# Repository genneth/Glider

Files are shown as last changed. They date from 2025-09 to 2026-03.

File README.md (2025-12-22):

# Glider

Open-source Eink monitor with an emphasis on low latency.

Note: This repo only contains the hardware design, the gateware running on the FPGA is my open-source [Caster EPDC](https://gitlab.com/zephray/Caster/) design. This README also contains information about the Caster as well.

Hardware Photo

This is a long document, containing not just information about this project, but also pretty much everything I know about Eink. Given it's a bit hard to gather information about Eink online, I think this is the right thing to do. Use the following table of contents to navigate around.

Eink is a registered trademark and brand of E Ink Corporation. All the contents provided in this repo are based on publicly available information online and original research. They are not endorsed by Eink in any way and they may contain errors and/ or inaccuracies. 

If you're interested in attaining a board, checkout the [product page for the Modos Paper Monitor on Crowd Supply](https://www.crowdsupply.com/modos-tech/modos-paper-monitor).

If you are interested in Eink or any other display technologies, I have a Discord server for that. Feel free to join: [https://discord.gg/rtT7euSHQS](https://discord.gg/rtT7euSHQS) . (This Discord server is also not endorsed by Eink or any other company. It's not a customer support server.) For Modos product support or other inqueries about Modos products, use [https://discord.gg/6ktE6VxSyh](https://discord.gg/6ktE6VxSyh).

## Table of Contents 

- [Overview](#overview)
    - [Features](#features)
    - [Hardware](#hardware)
    - [Components](#components)
- [Eink Screens](#eink-screens)
    - [Basic Theory of Operation](#basic-theory-of-operation)
    - [Advantages and Disadvantages](#advantages-and-disadvantages)
    - [The Role of Eink Controller](#the-role-of-eink-controller)
    - [Screen Panel Types](#screen-panel-types)
    - [Using Screen with Integrated Controller](#using-screen-with-integrated-controller)
    - [Using Screen without Integrated Controller](#using-screen-without-integrated-controller)
    - [Understanding Waveform](#understanding-waveform)
    - [Greyscale Display](#greyscale-display)
    - [Color Display](#color-display)
    - [Dithering](#dithering)
    - [Eink Screen Generations](#eink-screen-generations)
- [Caster/ Glider Design](#design-of-caster-and-glider)
    - [Low Latency Drive](#low-latency-drive)
    - [Hybrid Greyscale Mode](#hybrid-greyscale-mode)
    - [Limitations](#limitations)
    - [Hardware Design Decisions]()
    - [Gateware Architecture](#gateware-architecture)
    - [Firmware Functions](#firmware-functions)
    - [Resources Utilization](#resources-utilization)
- [Building](#building)
    - [PCB](#pcb)
    - [FPGA Bitstream](#fpga-bitstream)
    - [MCU Firmware](#mcu-firmware)
    - [Flashing Board](#flashing-board)
    - [Compatible Screens](#compatible-screens)
- [References](#references)
- [License](#license)
- [Appendix](#appendix)
    - [Using Screens without Datasheet](#using-screens-without-datasheet)
    - [Screen List](#screen-list)

## Overview

### Features

- Complete solution for low-latency/ high-refresh-rate EPD monitor
- Supports electrophoretic display panels with parallel I/F (Eink(R), OED and DES)
- Supports both monochrome and color-filter-array (such as Kaleido(TM)) based color screen
- Extremely low processing delay of \<20 us
- Supports binary, 4-level grayscale, and 16-level grayscale output modes
- Latency-optimized binary and 4-level grayscale driving modes
- Hybrid automatic binary and 16-level grayscale driving mode
- Host software runtime controllable regional update and mode switching
- Hardware bayer dithering, blue-noise dithering, and error-diffusion dithering with no additional latency
- Controller takes standard HVsync signal input
- Board-level design supports USB-C (USB Type-C DisplayPort Alt Mode) and DVI input

### Hardware

r0p7_mb

- Xilinx(R) Spartan-6 LX16 FPGA running Caster
- DDR3-800 framebuffer memory
- Type-C DisplayPort Alt-Mode video input with onboard PTN3460 DP-LVDS bridge or
- DVI (via microHDMI connector) video input with onboard ADV7611 decoder
- Epaper power supply with up to 1A peak current on +/-15V rail supporting large panels
- VCOM kick-back voltage measurement support
- On-board STM32H750 microcontroller for USB communication and firmware upgrade
- Up to 133MP/s processing rate with dithering enabled, >200MP/s when disabled

The board is designed with KiCad. You may need the latest stable version of KiCad to open the source file.

### Components

This repo hosts the PCB design and firmware source code. The RTL code is in a separate repo: [https://gitlab.com/zephray/Caster/](https://gitlab.com/zephray/Caster/).

## Eink Screens

Eink is the brand of a family of paper-like electrophoretic displays. The underlying technology is invented in the MIT Media Lab between 1995 and 1997 by Barrett Comiskey, J.D. Albert, and Joseph Jacobson. They later founded the E Ink Corporation to commercialize this technology.

Nowadays they are commonly used on e-readers and electronic shelf labels. You’ve probably seen them on Kindle, in stores, or maybe in some train stations as well.

| eReader/ Tablets | Electronic Shelf Label | Digital Signage |
|-|-|-|
| app_ereader | app_esl | app_signage |

(Source: https://www.eink.com/application, image copyright Eink corporation)

This section gives an overview of the electrophoretic displays, including the screen panels available and underlying technology. Note this project doesn't and can't support all electrophoretic screens. This documentation also solely focuses on using existing off-the-shelf screen panels rather than the physics or manufacturing process of one.

### Basic Theory of Operation

In the simplest form, you have charged particles with different colors, dispersed in some oil in some transparent container. By applying electric fields the particles can be moved up or down to produce either black or white, or a mixture of that.

eink-particle

(Source: https://www.eink.com/tech/detail/How_it_works , copyright Eink Corporation)

There are multiple technologies based on this basic concept, namely Eink’s micro-capsule display, SiPix (now acquired by Eink)’s micro-cup display, and WFT’s DES display. They differ in specific ways of confining the particles in containers, but otherwise very similar.

The pixels on the screen are typically arranged as a 2D array, driven with TFTs. The pixels are scanned/ driven periodically at a fixed refresh rate, typically ranging from 50Hz to 120Hz. Applying positive voltage on the pixel will typically drive the particles toward the white state while applying negative voltage will drive the particles towards the black state. This is similar to active matrix TN/IPS LCDs, which also use 2D TFT arrays and electrical fields for changing state. However, unlike LCDs, EPDs maintain their state after the electrical field is removed. So unlike LCDs which require continuous refreshing, the EPDs only need to be refreshed till the pixels are fully driven.

In terms of driving the screen panel, depending on the pixel value (1 or 0), each pixel would be driven either with a positive voltage or a negative voltage. A global counter can be used to count the frames elapsed and stop driving the pixels after a predefined period of time (for example, 100ms). Two framebuffers are typically used for determining if the pixel has changed color or not. If not, then the pixel does not need to be driven.

### Advantages and Disadvantages

In terms of display quality, EPDs are no match for modern IPS LCDs. The following is a comparison table of key parameters. The specific number would vary depending on the screen used but should be within the same ballpark.

| | Monochrome EPD | CFA-based Color EPD | Transmissive TFT IPS LCD | Reflective TFT TN LCD |
|-|-|-|-|-|
| Contrast Ratio | ~17:1 | ~14:1 | ~1000:1 | ~14:1 |
| Colors | 16 (Greyscale) | 4096 | 16M | 256 |
| Color Gamut | N/A | ~1.5% sRGB | ~99.9% sRGB | N/A |
| Reflectivity | ~45% | ~25% | N/A | ~15% |
| Response Time | ~150ms | ~150ms | ~10ms | ~15ms |

It has a few advantages. It reflects lights instead of emitting lights, so it generally consumes less power and can be used outdoors, etc. It’s also bistable, which means that it retains the image after the power has been removed. Personally, the biggest differentiating factor for me (author of this README) is that it looks like paper.

rlcd-vs-eink

The image above shows a comparison between reflective TFT LCD (SHARP memory LCD in this case) and Eink. The LCD has a mirror-like texture which changes reflectivity drastically in different angles, while the Eink is more paper-like.

| ZBD LCD | Ch LCD | STN LCD |
|-|-|-|
| zbd | chlcd | stnlcd |
| Bistable, reflective, high contrast, no greyscale, ~10s refresh | Bistable, reflective, lower contrast, up to 32 level greyscale, ~5s refresh | Volatile, reflective, lower contrast, up to 32 level greyscale, ~100ms response |

There are many other reflective or bistable display technologies. They are all interesting displays on their own, but none of them feels like paper (yet).

Overall, there is no single perfect display technology. Each has its own unique strength. Pick the right one for your project.

### The Role of Eink Controller

The Eink controller is in some ways similar to the display controller (DC/ CRTC) + timing controller (TCON) in a typical LCD-based system. It takes the raw image data and converts it to signals required to drive the screen.

eink-controller

To understand the actual work of an eink controller, start from the basic concept. The color of a pixel can be changed by applying positive or negative voltage for a finite period of time. From the controller’s perspective, depending on the current state of the pixel and the desired state of the pixel, there are 4 possibilities.

| Current State | Target State | Action |
|-|-|-|
| Black | Black | No operation |
| Black | White | Apply positive voltage |
| White | Black | Apply negative voltage |
| White | White | No operation |

The controller needs to store and maintain the screen state inside of its own buffer memory, so it would typically have a large on-chip SRAM or an off-chip SDRAM controller. The controller should also have a timer to ensure the screen doesn't get overdriven or underdriven.

The controller often uses the so-called "[waveform](#understanding-waveform)" to replace the action column of the previous table. Instead of hardcoding the action for state transition, the actions are stored into a look-up-table (LUT) which can be modified at runtime to allow higher flexibility.

Controllers may also offer more advanced features such as [dithering](#dithering) acceleration, multiple region updates, automatic LUT selection, etc.

### Screen Panel Types

As discussed in the previous section, an Eink screen needs to be coupled to an Eink controller to function. Aside from that, the screen also needs high-voltage drivers to drive the TFTs and the pixels. Virtually all E-paper panels use either COG (Chip-on-Glass) or TAB (Tape Auto Bonding) to integrate some chips onto the screen panel itself. Most of the screens available today can be divided into two categories based on whether or not the controller is integrated in:

screen-types

Here is a non-exhaustive list of the types based on their size: (the size or resolution is not related to or limited by the type, it is just for a certain size, and the vendors tend to make them the same type.)

- Screens without controller: 4.3", 6.0", 7.8", 8.0", 9.7", 10.3", 13.3", 25.3", 31.2", 42"
- Screens with controller: 1.02", 1.54", 2.13", 2.6", 2.9", 3.71", 4.2", 5.65", 5.83", 7.5", 12.48"

One may notice that almost all e-readers/ e-ink cellphones use screens without controllers, while almost all e-ink electronic shelf labels (ESL) use screens with controllers. This gives some hints about the advantages and disadvantages of two types:

| | Without Controller | With Controller |
|-|-|-|
| System Cost | High. A dedicated controller or SoC with an integrated controller is usually required. Needs a dedicated power supply. | Low. Virtually any MCU could drive the screen directly, and the power supply is integrated in. |
| Greyscale Levels | Generally 16 (4bpp), up to 32 (5bpp) | Generally 2 (BW only) or 4 (2bpp), with some hack, up to 16 (4bpp) |
| Refresh Speed | Generally fast (100ms~300ms) for BW. Depends on the screen used and the system architecture | Generally fast (100ms~300ms) for BW if the partial refresh is enabled. Greyscales are much slower, BWR or BWY screens would be even slower.
| Total Update Latency | Generally the same as refresh time. Depends on the system architecture | Slow. Ranging from 100ms to several seconds based on the resolution. |

Please keep in mind the discussion is about off-the-shelf screens you can buy today. These tradeoffs do not necessarily come from the fact the controller is integrated or not.

Note that I mentioned the refresh speed and total update latency. They are different:

The refresh speed refers to the time it takes to start refreshing the screen: from starting to seeing screen changing, to the screen finish showing the new content.

The total update latency refers to the latency when the processor needs to update the screen, to the screen finish showing the new content. As you can see, this is the biggest issue for screens with controllers. This is the main reason why they are rarely used on e-readers cell phones or PC monitors.

screen-controller-diagram

This diagram illustrates the difference between the two. It should be noted that the screens without controllers have the flexibility to be driven quickly, but the system designer might not architect the system for low latency.

### Using Screen with Integrated Controller

Screens with integrated controllers have almost everything already integrated. Common display panels of this type only need a few external capacitors, inductors, and MOSFETs to support the integrated bipolar power supply circuit, then it could be hooked up to MCUs or MPUs using common interfaces like SPI or I2C. There are a lot of driving boards and examples of these screens available online.

To be expanded (TODO)

### Using Screen without Integrated Controller

This could get complicated. Note I used a lot of "generally" in the previous comparison table because there are many things one could do to drive them. Some of them would certainly impact the performance. The main issue here is the controller chip. There are three solutions to drive these screens:

- Using a dedicated controller chip to drive the screen
- Using an SoC that has an integrated controller
- Using a fast MCU/SoC to emulate the controller with GPIO (software timing controller)

Then, again here is a comparison between them:

| | Specialized controller chip | SoC with integrated controller | MCU + Software TCON |
|-|-|-|-|
| Resolution | UXGA+ | UXGA+ | Limited by MCU RAM. Up to XGA with SRAM, UXGA with PSRAM, UXGA+ with DDR |
| Greyscale | Up to 32 | Up to 32 | Up to 32 |
| Partial Update | Yes | Yes | Yes |
| Total Update Latency | Depends. Could be very close to refresh speed, could be slow like screens with controller | Same as refresh speed | Same as refresh speed if data is internally generated (not streaming from an external device such as a PC) |
| Suitable Applications | IoT devices, E-readers, cellphones, E-ink monitors. possibly E-ink laptops | Advanced IoT devices, E-readers, cellphones, E-ink typewriters, possibly lower performance E-ink laptops | When using MCU: IoT devices, large ESLs, simple DIY E-readers. When using MPU: Same as SoC with integrated controller |

When using a dedicated controller, it could accept data from external devices. This allows it to be used in various different types of applications. Ranging from IoT devices, and ESLs, to PC monitors with relatively fast refresh rate and low latency.

When using SoC or MCU, the display content is generated by the SoC or MCU itself, which ultimately is limited by the capability of the SoC or MCU. Given the current SoCs with E-ink display controllers are usually limited in performance, the application is limited. The same goes for MCU, it does what an MCU could do. You could find ways to stream video data into SoC or MCUs by using USB, camera interface, WiFi, etc., but this might not be optimal.

#### Existing Solutions

- Specialized controller chip
    - Closed-source
        - EPSON S1D13xxx: Widely used EPD controller in early E-readers. Proprietary, no documents available. Probably EOL.
        - IT8951: Used on the waveshare EPD Hat. Documents are available. It works with large EPDs up to 2048x2048. The drawback is the speed as the interface between processor and IT8951 could be slow. This is similar to the situation on screens with integrated controller
        - T1000: Also known as IT8957, upgraded model of IT8951. It supports even higher resolution. It features a higher speed MIPI DSI interface to mitigate the slow speed of IT8951.
        - Waveshare HDMI driver board: FPGA-based controller. Closed source but easily purchasable, could be integrated into larger projects as a module.
    - Open-source
        - This project (Caster + Glider): FPGA-based controller, multiple update modes, ultra-low latency processing, and wide range of screen support.
        - https://hackaday.io/project/21607-paperback-a-desktop-epaper-monitor: FPGA-based controller. However, doesn't support partial update mode and slower speed.
        - https://hackaday.io/project/21168-fpga-eink-controller: FPGA-based controller supports vendor waveform with reasonable speed.
- SoC with integrated controller
    - RK29xx: Fairly old, Cortex-A8 based (RPi 1 level performance), 55nm, EOL
    - RK3026/RK3028: Fairly old, Cortex-A9 based (RPi 2 level performance), 40nm, EOL
    - i.MX 50: Fairly old, Cortex-A8 based (RPi 1 level performance), 65nm, in production
    - i.MX 6ULL: Cortex-A7 based (RPi 1 level performance), 40nm, in production
    - i.MX 6S/D: Fairly old, Cortex-A9 based (RPi 2-3 level performance), 40nm, in production
    - i.MX 7S/D: Cortex-A7 based (RPi 2 level performance), 28nm, in production
    - i.MX 8ULP: Cortex-A35 based (RPi 2 level performance), 28nm FD-SOI, in production
    - AW B200: Cortex-A53 based (RPi 2 level performance), 28nm, in production
    - MT8113: Cortex-A53 based (RPi 2 level performance), 12nm, in production
    - RK3566/RK3568: Cortex-A55 based (RPi 3 level performance), 22nm, in production
    - RK3576: Cortex-A72 + A53 based (RPi 4-5 level performance), 8nm, in production
- MCU/SoC + Software TCON
    - http://essentialscrap.com/eink/waveforms.html: One of the earliest e-ink hacks. Limited in performance but still could be used as a reference
    - NekoCal: One of the earliest e-ink software TCON with greyscale support. Used to be available as a DIY kit. No longer updated, still could be used as a reference
    - InkPlate 6/10: Commercially available. Based on ESP32.
    - EPDiy: Based on ESP32, supports a lot of different screens, recommended if want to build some device with ESP32+Eink or embed it into a larger project.

#### Interface Signals and Timing

The interface signals and timing are fairly similar to LCDs without a controller. Following is the list of signals typically found on EPDs:

- GDOE/ MODE: Gate driver output enable
- GDCLK/ CKV: Gate driver clock (like HSYNC in LCD)
- GDSP/ SPV: Gate driver start pulse (like VSYNC in LCD)
- SDCLK/ XCL: Source driver clock (like PCLK in LCD)
- SDLE/ XLE: Source driver latch enable (like HSYNC in LCD)
- SDOE/ XOE: Source driver output enable
- SDCE/ XSTL: Source driver start pulse (like DE in LCD)
- SD: Source driver data (8-bit or 16-bit)

SD signals go into the source driver, typically in the X direction. GD signals go into the gate driver, typically in the Y direction. It's a 2D array, the gate driver selects one line at a time, and the source driver outputs the voltage for all the pixels in that line.

Conceptually, it's like a raster scan on a CRT. To send one field of data, both GD and SD are reset to the start position by using the start pulse signal. Data are then transmitted into the source driver 4 or 8 pixels at a time. Once the line has been fully transmitted, the source driver is reset to the beginning position by a start pulse signal, and the gate driver moves to the next line by a pulse on the gate driver clock. Once all lines have been scanned, the entire process repeats for the next field.

One notable difference with LCD is that each pixel is represented by 2 bits. This, however, doesn't mean each pixel is 2bpp or 4-level greyscale. The 2-bit per pixel is used to encode the voltage applied to the pixel:

- 00: No voltage
- 01: Negative voltage
- 10: Positive voltage
- 11: No voltage

Just like CRT/ LCD, there are also blanking periods in the entire timing (which means it's just waiting without active pixel data being sent). They have identical meanings to CRT/ LCD systems:

display-timings

(Source: https://projectf.io/posts/video-timings-vga-720p-1080p/, Copyright Will Green)

The following is a piece of pseudo-code implementing the Eink timing:

```c
#define DATA_BUS_WIDTH      8 // 8bit wide bus
#define PIXEL_PER_CYCLE     (DATA_BUS_WIDTH / 2)
#define VFP     12  // Vertical front porch
#define VSYNC   1   // Vertical sync length
#define VBP     2   // Vertical back porch
#define VACT    758 // Vertical active lines
#define HFP     72  // Horizontal front porch
#define HSYNC   2   // Horizontal sync length
#define HBP     2   // Horizontal back porch
#define HACT    (1024 / PIXEL_PER_CYCLE)

void pulse_h_clock() {
    sdclk = 1;
    sdclk = 0;
}

void drive_line(bool v_in_act) {
    sdce = 1;
    gdclk = 0;
    for (int i = 0; i < HFP; i++) pulse_h_clock();
    sdle = 1;
    gdclk = 1;
    for (int i = 0; i < HSYNC; i++) pulse_h_clock();
    sdle = 0;
    for (int i = 0; i < HBP; i++) pulse_h_clock();
    if (v_in_act) sdce = 0;
    for (int i = 0; i < HACT; i++) {
        send_data();
        pulse_h_clock();
    }
}

void drive_frame() {
    gdoe = 0;
    sdoe = 0;
    gdsp = 1;
    for (int i = 0; i < VFP; i++) drive_line(false);
    gdsp = 0;
    gdoe = 1;
    sdoe = 1;
    for (int i = 0; i < VSYNC; i++) drive_line(false);
    gdsp = 1;
    for (int i = 0; i < VBP; i++) drive_line(false);
    for (int i = 0; i < VACT; i++) drive_line(true);
}
```

More explanation can be found at [http://essentialscrap.com/eink/index.html](http://essentialscrap.com/eink/index.html)

### Understanding Waveform

The waveform is a look-up table for the eink controller to determine how to drive the pixels, mostly useful for greyscale image display, but generally used for binary image display as well.

The look-up-table has 3 inputs (dimensions): frame number, source grayscale level, and destination grayscale level. During the update process, for a certain pixel, the source and destination level stays the same, and the frame number increases each frame. The look-up process is done for every pixel every frame. The controller may choose different LUTs depending on the ambient temperature. Mode switching is also implemented by simply switching between different LUTs.

This is essentially what typically eink controller does. For each pixel, look up in the table to determine the voltage to use. Repeat this for a couple of frames with an incrementing frame counter, until all pixels are fully driven.

It should be obvious that the waveform file itself is independent of the resolution as the waveform only cares about a single pixel. With an incorrect or un-optimal waveform, the screen should at least display some recognizable image.

#### Waveform Example

There are several sample waveform tables provided in the project repo. Take the GC16 (Greyscale clearing 16-level) waveform of GDEW101C01 as an example: https://github.com/zephray/NekoInk/blob/master/waveform/gdew101_gd/test_M2_T0.csv

Take one line from that file:

```6,13,0,0,0,0,0,0,0,0,0,2,1,1,1,1,1,1,1,1,1,1,2,2,2,2,2,2,2,2,2,2,2,2,2,2,2,2,1,0```

This means from greyscale level 6 to level 13, it needs to go through the following sequence. Each number means the operation on that frame, 0 is no-operation, 1 is darken, and 2 is lighten. In this case, there are 38 frames, first 9 frames do nothing, then lighten for 1 frame, darken for 10 frames, lighten for 16 frames, and finally darken for 1 frame and have no operation for the last frame. This is the sequence to change a pixel from level 6 to level 13. Such lookup is done for every pixel on every frame.

#### Waveform Modes

To give system designers more flexibility, Eink controllers often offer multiple "modes", like binary mode, 16-level grayscale mode, 16-level grayscale mode with reduced flashing, 4-level grayscale mode, etc.

The waveform provided by Eink has many modes. There is a good document from Eink describing the modes:

https://www.waveshare.net/w/upload/c/c4/E-paper-mode-declaration.pdf

It provides a good overview of the modes. I am just going to add some comments.

- GC in the GC16 stands for "greyscale clearing". GC does not stand for greyscale. There are 16-level greyscale modes that aren't called GC16.
- Officially there are no 32-level greyscale modes (yet). There are 5-bit waveforms, which means they internally use 5 bits for each pixel, which potentially allows up to 32-level greyscale, but no such waveform exists (yet).
- There are no 16-level greyscale modes without flashing. The DU4 is the only greyscale mode that's non-flashing.
- The GL16 mode, as described, only works for black text on a white background. When refreshing greyscale images, the GL16 is similar to the GC16.
- The GLR16 mode is also called the REGAL mode, and the GLD16 mode is also called the REGAL-D mode.
- Eink doesn't even know if it should be spelled as REAGL or REGAL:  Google search "REAGL site:eink.com" and "REGAL site:eink.com" both returned several results.
- Eink-provided waveform usually implements all these modes, however it is not always required. The waveform file may also contain waveform tables in other orders.
- In terms of the waveform, the waveform for GL16, GLR16, and GLD16 are identical. This is expected, the REGAL requires an additional algorithm on the host image processing and is not a technology based on tweaking the waveform.

#### Obtaining Waveform

In general, the screen vendor (Eink, Good Display, etc.) should provide the waveform file.

If your screen has a flash chip on it, it's also possible to extract the waveform from a flash dump:

```dd if=somedump.bin of=waveform.wbf bs=1 skip=2182```

If you have access to an application board, it might also be possible to extract the waveform there. For example, if the system uses a T1000/T2000/T2001 controller, the waveform is usually stored in the SPI flash connected to the controller. Some times the waveform stored on the flash is compressed (in addition to the RLE compression already applied to the waveform file itself).

#### Waveform Formats

E-Ink distributes waveforms in the wbf file format. SoC/ Eink controller hardware often requires converting the file into a vendor-specific file format. Caster/ Glider also uses a specific binary format. This project defines a common human-readable format (Interchangeable Waveform Format, IWF) and provides several tools for working with different binary formats and the IWF format.

#### Interchangeable Waveform Format

The waveform consists of one descriptor file in iwf extension (ini format) and various lut data files in csv format.

The descriptor contains the following required fields:

- VERSION: the version of the descriptor (should be 2.0)
- NAME: (optional) original name for the waveform
- BPP: (optional, default 4) 4 or 5, representing the internal state count used for waveform
- PREFIX: the filename prefix for actual waveform files
- MODES: the total modes supported by the waveform
- TEMPS: the total number of temperature ranges supported by the waveform
- TxRANGE: the supported temperature in degC, where x is the temperature ID
- TUPBOUND: (optional) upper bound for temperature range, each range is TxRANGE to Tx+1RANGE (or TUPBOUND in case of the last one)
- TABLES: total number of LUTs inside the waveform
- TBxFC: the frame count for the table, where x is the LUT ID

Each mode has its own mode section named [MODEx], where x is the mode ID, containing the following fields:

- NAME: the name for that mode
- T*TABLE: the table used for the temperature in that mode

There should be a number of LUTs, saved in the filename like PREFIX_TBx.csv, where x is the LUT ID. Each csv file should contain a LUT like this: lut[src][dst][frame], which means, to transition from src greyscale level to dst greyscale level, at a certain frame in a frame sequence, what voltage should be applied to the screen (0/3: GND / Keep, 1: VNEG / To black, 2: VPOS / To white). Each line contains the frame sequence for one or more source-to-destination pairs.

For example:

- ```4,7,1,1,1,0,2``` means to transition from greyscale level 4 to greyscale level 7, there should be 5 frames, each applying VNEG VNEG VNEG GND VPOS
- ```0:14,15,2,2,2``` means to transition from any greyscale level between 0 and 14 to greyscale level 15, there should be 3 frames, each applying VPOS VPOS VPOS

These are provided to only illustrate the file format, they are not valid or meaningful Eink driving sequences.

#### Converting Between Waveform Formats

The following converters are provided in the repo:

- To convert from iwf to fw (iMX6/7 EPDC format): ```./mxc_wvfm_asm v1/v2 input.iwf output.fw```
- To convert from fw to iwf: ```./mxc_wvfm_dump v1/v2 input.fw output_prefix```
- To convert from wbf to iwf: ```./wbf_wvfm_dump input.wbf output_prefix```

#### Waveform Tweaks

Some commercial implementations allow users to reduce the frame count and/ or alter the waveform playback speed, so the user can trade between contrast ratio and frame rate.

### Greyscale Display

Other than full white and full black, with appropriate modulation, Eink screens can also display some levels of greyscale (typically 16).

![greyscale](assets/eink_32g.jpg)

For grayscale displays, the basic idea is simple. If the pixel is not fully driven (say only drives for 50ms while it takes 100ms to reach full black/ white), it would stay in a gray state.

There are two ways of achieving this modulation:
- Modulate the frame time
- Modulate the number of frames with constant frame rate

Both are possible, as described below

#### Frame Time Modulation

This method changes the drive time by changing the length of a single frame. The screen would only be driven for 15 or 31 frames for 16-level and 32-level greyscale, but the frame time (thus frame rate) is altered to provide the desired driving time. The LUT would be a one-dimension look-up table, only containing the incremental time required to drive to the next greyscale level. The source/ gate driver output enables the line to be toggled to achieve the desired driving time.

This method doesn't seem to be implemented in any commercial solutions and is significantly slower than the second method. But it certainly works. The 32-level greyscale demo shown in the picture above is achieved using this method.

#### Frame Count Modulation

This method changes the drive time by changing the number of frames being applied to the screen. The screen is still being driven at a constant frame rate. The following is a simplified hypothetical waveform table for achieving 4-level greyscale:

| Previous State | Target State | Frame 0 | Frame 1 | Frame 2 | Frame 3 | Frame 4|
|-|-|-|-|-|-|-|
| Black | Black | NOP | NOP| NOP | NOP | NOP |
| Black | Dark Grey | VPOS | VNEG | VPOS | NOP | NOP |
| Black | Light Grey | VPOS | VNEG | VPOS | VPOS | NOP |
| Black | White | VPOS | VNEG | VPOS | VPOS | VPOS |

Note how it alternates between VPOS and VNEG in the beginning. This is often called the "activation phase" to improve the contrast ratio. Putting this detail aside, it changes the number of VPOS frames to settle down on different grey levels.

The actual grayscale driving sequence used in the commercial implementation is more complex than that, often involving switching the pixel towards black/white a few times before settling. This design is partially due to the limited time control granularity and other temperature/ manufacturing variance-related concerns. Some side-effects of such a driving sequence are that the refreshing process is “flashing”, and is slower compared to displaying only a 1-bit binary image.

### Color Display

There are several different technologies that could be used to build full-color EPDs. The 2 most common ways are to use a color-filter-array (CFA) or use a multi-pigment color display.

The following picture has a CFA-based color screen (Kaleido 3) on the left, and a multiple pigment color display (Spectra 6) on the right, displaying the same image.

![sp6vsk3_2](assets/isabella.jpg)

![sp6vsk3](assets/kaleido3spectra6.jpg)

(Yes the left one IS a color screen!)

#### Color Filter Array

CFA stands for color filter array, which is colored glass/ film on top of the screen pixel. This is also the technology used on most color LCDs. Eink Kaleido, Eink Triton, and color DES are based on this technology. The main advantage is that it's relatively simple to control, and the low-level driving is the same with the greyscale panels. Thus it has the same level of refreshing time (100~200ms), and the same level of greyscale (16 level translate to 16^3=4096 colors). The drawback is that the CFA filters out some light (due to its colored nature), and the screen reflectivity is negatively affected by the CFA. The screen ends up being quite dark. Up to now, most color E-readers use CFA-based displays. This project supports all three major types of CFA-based EPD screens: color DES screen, Eink Triton, and Eink Kaleido.

#### Case Study: GDEW101C01 (CFA-based, DES)

The GDEW101C01 is a 10.1" color DES screen made by Good Display / WeiFeng Tech. It uses CFA to produce color images. As a result, to the eink controller hardware, it's just a normal greyscale panel with a bunch of pixels. However, the pixels are colored depending on their location due to the CFA. The coloring of the pixels can be either handled by hardware or software.

##### Pixel Arrangement

Color DES is a bit different from a typical color TFT LCD in terms of CFA design. Typically on TFT LCDs, one RGB pixel is called a pixel, and each R/G/B component is called as a sub-pixel. On color DES, the sub-pixel ends up being called a pixel, and each pixel is either red, green, or blue. In the display industry, such pixels are more commonly referred to as dots.

![subpixel](assets/subpixel.jpg)

Pengo, CC BY-SA 3.0 https://creativecommons.org/licenses/by-sa/3.0, via Wikimedia Commons

The actual photo of the DES panel under the microscope:

![color-des](assets/color_des.jpg)

In the above photo, the DES pixel arrangement is the same as the OLPC XO-1. Notably, many Eink's Kaleido 3 (but not all) also uses the same pixel arrangement.

Having no subpixel / each pixel only has 1 color doesn't necessarily mean that the effective resolution needs to be divided by 3. This arrangement is slightly more "efficient" than the RGB strip in terms of perceptive resolution. You can find a more detailed analysis in the paper Comparing the Effective Resolution of Various RGB Subpixel Layout.

##### Processing image for Color DES

If the image is displayed on color DES without any processing, it would look like a greyscale image. This is similar to when you just send the same color value to R/G/B components on a color LCD.

To get color, there are 2 possible solutions:
- Treat 4 pixels as a group of a single pixel, and each physical pixel is now considered as a subpixel.
- Treat each pixel as an independent pixel, but send only the color component that corresponds to the pixel color.

Depending on how you classify pixel and subpixel, the 2nd method can also be viewed as a mean of 2X supersampling subpixel rendering.

In general the 2nd method offers better resolution especially in text:

| Method 1 | Method 2 |
|-|-|
| ![des_without_spr](assets/des_without_spr.png) | ![des_with_spr](assets/des_with_spr.png) |

The following discussion are all about the 2nd method: render at full resolution, but only use 1 color component for each pixel.

![pixel-layout](assets/PixelLayoutDiagonal.png)
(Source: https://wiki.laptop.org/go/File:PixelLayoutDiagonal.png, public domain)

For example, for pixel 01, the pixel on the screen is green. Then only the green component from the frame buffer should be sent to the screen.

To get a basic 4096 color image display, this is everything needed. However generally to improve image quality, a few more steps are applied:

##### Low pass filtering

The previously described image-displaying process is essentially a down-sampling process for each color component: Only 1/3 of the pixels are sent to the screen. Then this becomes a classic signal processing issue: sampling the signal would cause frequency components above Nyquist to fold back to the low frequency part. Or in simpler words, you would see jagged edges/ aliasing, which are things that weren't present in the original image. To prevent this, low pass filtering (blurring) needs to be applied first to the image to remove these high-frequency components. The following diagram from the OLPC wiki shows a simple way of implementing a such filter:

![pixel-proc](assets/PixelProcDiagonal.png)
(Source: https://wiki.laptop.org/go/File:PixelProcDiagonal.png, public domain)

##### Dithering

Dithering can be applied to further improve image quality. See the dithering section for more details.

#### Multi-Pigment Color Display

Another technology for implementing color EPD is by using a multi-pigment color display. This is a technology developed initially by SiPix and further improved by Eink. The basic idea is to use ink particles with different colors inside a single pixel. By applying a sequence of voltages, the ink particles can be arranged to display different colors.

![spectra6](assets/eink_spectra6.jpg)

(Source: https://www.eink.com/tech/detail/How_it_works , copyright Eink Corporation)

One major advantage of this solution is it can achieve higher resolution (because it doesn't have a CFA, so no resolution reduction), higher reflectivity (because it doesn't have a CFA, so no light loss), and higher color saturation (because it doesn't have a CFA, no need to play the reflectivity vs saturation trade-off game).

Eink has 2 lines of products using this Technology, Eink Gallery and Eink Spectra. The advantage is it's much brighter compared to CFA-based solutions. The disadvantage is it's much more difficult to drive, and quite slow: 1st /2nd gen Eink Gallery screen takes 30s (!) to refresh, and Spectra 6 Plus devices take 7s to refresh. It's possible to trade in some color saturation for higher speed, though still much slower than CFA-based solutions. The specific product lines will also be discussed in [Eink Screen Generations](#eink-screen-generations)

##### How ACeP Waveform Works

To be written (TODO)

##### How to get more colors on ACeP

This is possible with a modified waveform.

To be written (TODO)

##### Fast ACeP

While ACeP screens have been generally slow to refresh (15-30s), Eink has tried to improve that. In 2022 Eink released their Gallery 3 lines of ACeP screens, which promised sub 1 second update time. [ACeP was supposed to be the "next big thing" in ereader](https://arstechnica.com/gadgets/2022/04/new-e-ink-gallery-displays-could-finally-make-full-color-e-readers-good/). Back in the end 2022, Eink announced that ["Gallery 3 has moved into mass production, with customer products from Bigme, BOOX, iFlyTek, iReader, PocketBook, Readmoo, and AOC coming down the pipeline in 2023 and beyond"](https://www.e-ink-info.com/e-ink-gallery-3-acep-color-epaper-displays-move-mass-production).

How well does it do? Just talking about the screen, it's not looking good. It suffers from poor reflectivity and poor saturation to a point where it's not much better than Kaleido:

![gallery3_kaleido](assets/gallery3_kaleido_plus.jpg)

(Original illustration copyright MiHoYo)

The difference between Gallery 3 and Gallery Palette (which is supposed to be a lower-end product) is also stunning:

![acep_comparison](assets/gallery3_gallerypalette.jpg)

The one on the left is the Gallery 3 used on eReaders, and the one on the right (brighter and more saturated one) is the Gallery Palette used on ESLs. Though to be honest I hacked the right one a bit to display 512 colors opposed to the stock 7 colors. If Gallery 3 had the same image quality as previous ACeP/ Gallery screens, it would make sense to trade in response time for better image quality. But it doesn't.

##### Future of ACeP

While as previously referenced that Eink was hoping to ship lot of Gallery 3 based E-readers in 2023, 2023 passed with exactly one product, the Bigme Galy, with mixed receptions. Early 2024, it was announced that [Bigme Galy has been discontinued](https://goodereader.com/blog/electronic-readers/bigme-galy-is-discontinued), and [Eink has announced EOL for certain ACeP-based products](https://www.ineltek.com/wp-content/uploads/2024/04/EInk_AC073TC1_EOLNoticeLetter_notice_20240401.pdf). But ACeP is not dead yet.

Going forward, Eink has 3 different line-ups for different markets:
- Eink Marquee for outdoor signage
- Eink Spectra for electronic shelf labels and advertisements
- Eink Gallery for e-readers and e-notebooks

All of these lines are direct offspring of the original ACeP screens:
- Eink Marquee uses the same color composition as the ACeP, but replaces the SiPix-style micro-cup with micro-capsule
- Eink Spectra uses similar structure as the ACeP, but replaces color composition
- Eink Gallery is the original ACeP line up

In 2024, we saw the release of reMarkable Paper Pro, which is a 11.8" Gallery 3 e-notebook. ACeP screens are still in production and we might be able to see more products in the future.

##### Spectra 6

Compared to the Gallery lines, Spectra 6 uses a very similar multiple pigment system. But instead of using cyan, magenta, and yellow as the base colors, Eink switched to use red, yellow, and blue instead. Officially the color gamut volume stays the same, but the contrast ratio gets boosted up to 22:1 from 10:1, mainly due to darker black. Reflectivity stays the same at around 35%, lower than Carta products, but still far better than CFA based ones.

(TODO: Compare image quality between Sp6 and GalleryPlus)

### Dithering

Eink and DES panels typically only support up to 16 levels of greyscale with the vendor-provided waveform. To improve response time, or to avoid flashing images, a binary (1-bit, 2-level) display is also used. Dithering could be applied to produce better images (increasing SNR, in signal processing sense).

The following is applying dithering to a simple black-to-white gradient. Note the results are not optimal due to limitations in quantization and incorrect gamma correction. But the idea is the same.

| Original | Binary No-dithering | 2 Row Sierra Dithered |
|-|-|-|
| ![original](assets/grad_orig.png) | ![nodither](assets/grad_no_dither.png) | ![errordiffusion](assets/grad_ed.png) |

Dithering can help when the screen has a native 16-level greyscale as well:

| Original | 16 Level Greyscale No-dithering | 16 Level Greyscale Dithered |
|-|-|-|
| ![original](assets/grad_orig.png) | ![nodither](assets/grad_4bpp_nd.png) | ![errordiffusion](assets/grad_4bpp_ed.png) |

As you can see, the non-dithered image loses all the greyscale in between, while the dithered version on the right gives the illusion of greyscale while only using full black and full white colors.

To understand it further, take the following example:

Say the source image is 30% brightness (or 0.3). This cannot be displayed on a binary screen which can only display 0% (0.0, black) or 100% (1.0, white) brightness. A simple thresholding process is added to determine if the screen should display 0 or 1 by checking the incoming brightness. If it's less than 0.5 then the display brightness is rounded down to 0, otherwise 1. Because 0.3 is always lower than 0.5, the whole screen displays 0 (black).

This is less than ideal. A better way is to set around 30% of the pixel black, while 70% of the pixel white. Different dithering algorithms can be used to achieve this 30/70 distribution. Two common methods used are ordered dithering and error-diffusion dithering, which will be described below.

#### Ordered Dithering

The ordered dithering adds a pre-computed/ fixed texture to the image before the thresholding process. In other words, it basically adds some noise to the image. This may sound weird initially, but it should be easy to see the effect of noise in the example.

Using the example previously described displaying 30% brightness grey on a binary screen. The goal is to let the rounding process end up with 0 for 30% of the time and 1 for 70% of the time. This could be achieved by adding a noise. In the simplest case, a random number with a uniform distribution between [-0.5, 0.5] is added to the incoming brightness. The brightness has a value of 0.3, when adding this number to the random number, the random number now has a uniform distribution between [-0.2, 0.8]. The threshold is still set to 0.5, and now the probability distribution can be seen as below:

![pdf](assets/dithering_pdf.svg)

The pixel now has a 30% chance of being rounded up to 1, and a 70% chance of being rounded down to 0. Before dithering, it would always be rounded down to 0.

However, a purely random number is generally not the best noise to use. Bayer dithering matrix and blue noise are more commonly used, with the results as illustrated below. The idea is the same, but instead of adding random numbers, a pre-computed number from the Bayer dithering matrix (array) or blue noise texture (array) is added to the image.

| Random Dithering| Bayer Dithering | Blue-noise Dithering |
|-|-|-|
| ![random](assets/grad_rand.png) | ![bayer](assets/grad_bayer.png) | ![bluenoise](assets/grad_bn.png) |

#### Error-Diffusion Dithering

The basic idea is when rounding down the color (selecting the closest color from the 16-level greyscale from 256-level input), the error value (difference) is calculated and added to neighboring pixels (so this error would be considered when processing these pixels later). The whole process is called error-diffusion.

Still using the previous example of a 30% brightness image, and assume an extremely simple dither kernel: diffuse all error to the next pixel. Let's see it in action.

In the first pixel, 0.3 (image brightness) is less than 0.5 (threshold), so it's displayed as 0 (black). This introduces a 0.3 error: the displayed color is 0.3 darker than the requested color. So 0.3 is being diffused to the next pixel, hoping the next pixel can correct the error.

Onto the second pixel. The value is 0.3 (image brightness) + 0.3 (diffused error) = 0.6. It's now larger than 0.5 (threshold), so it's displayed as 1 (white). This introduces a -0.4 error: the displayed color is 0.4 brighter than the requested color. -0.4 will be diffused to the next pixel.

For the 3rd pixel, the value is now 0.3 - 0.4 = -0.1. This is less than 0.5 and displayed as 0 (black). Error -0.1 is diffused further.

And this process just goes on. With enough pixels, eventually, it would yield about 30% of white pixels and 70% of dark pixels.

Similar to how random value is not the best thing to do in ordered dithering, dithering to the right is also less than ideal. It creates very repetitive patterns. I mentioned the word kernel. Error diffusing uses a diffusion kernel, which specifies the target and percentage of the diffused error. There are many classic kernels, such as Floyd-Steinberg, Stucki, Sierra, etc. commonly used for image dithering. They all diffuse to more than 1 pixel to improve the overall look of the image. As shown below, even just diffusing the error to 2 pixels (half of the error goes to the pixel on the right, and the rest half of the error goes to the pixel on the bottom) yields a much better result:

| Dither to Right | Right and Down | Floyd-Steinberg |
|-|-|-|
| ![right](assets/grad_naive.png) | ![rightdown](assets/grad_naive2.png) | ![fs](assets/grad_fs.png) |

#### Applying Dithering on CFA-based Color Screens

Dithering can be applied on CFA-based color screens such as Eink Kaleido and color DES screens as well. The following is on a simulated DES screen: (The left original is assuming the screen has a native 24bpp color, still on a simulated screen)

| 16M color DES (does not exist) | 8-color DES | 8-color DES Dithered |
|-|-|-|
| ![original](assets/color_8bpp.png) | ![nodither](assets/color_nd.png) | ![errordiffusion](assets/color_ed.png) |

Ordinary dithering kernels don't work too well on color screens. For example, the error-diffusion dithering process pushes/ diffuses error neighboring pixels without considering their color. Ideally, it should push/ diffuse the error only to pixels with the same color. This is fairly easy to fix though, by tweaking the kernel it would achieve good results on CFA-based screens as well. (I am going to shamelessly call it Wenting's kernel)

| 16M color DES (does not exist) | 8-color DES naively apply Floyd-Steinberg (wrong) | 8-color DES with Wenting's kernel |
|-|-|-|
| ![original](assets/color_8bpp.png) | ![original](assets/color_fs_wrong.png) | ![errordiffusion](assets/color_ed.png) |

Of course, one can apply Bayer-like ordered dithering, blue noise dithering, or dithering on 4096-color mode as well:

| 8-color DES Bayer-like | 8-color DES Blue-noise | 4096-color DES Error-diffusion |
|-|-|-|
| ![original](assets/color_bayer.png) | ![original](assets/color_bn.png) | ![errordiffusion](assets/color_4bpp_ed.png) |

It's called bayer because, similar to how naively doing error diffusion doesn't work, the bayer matrix has to be modified to work on the color screen.

#### Gamma Correction

Another thing to consider is gamma. The dithering process involves a step of selecting the closest value. However, selecting the closest numerical value does not necessarily mean the closest color. The image typically is in sRGB space, which is non-linear. This causes the simple rounding to pick the wrong color, also calculating the wrong error value. One solution is to work in the linear space. This is also known as gamma-aware dithering. You could read more related info online, for example here: [https://learnopengl.com/Advanced-Lighting/Gamma-Correction](https://learnopengl.com/Advanced-Lighting/Gamma-Correction).

![dither-gamma](assets/dither_gamma.jpg)

The difference is quite evident when dithering down to 1 bit for a color screen. The top left is the original image, the top right is dithering in the sRGB space, and the bottom left is dithering in the linear space.

#### Further Reading

See [https://en.wikipedia.org/wiki/Dither](https://en.wikipedia.org/wiki/Dither) for more information about dithering.

### Eink Screen Generations

Depending on how you count, there are multiple generations of Eink screens commercially available. For monochrome screens before 2023, it's possible to tell the generation by looking at the 6th digit on the serial number:

![eink_serial](assets/eink_serial.jpg)

That is the FPL code in the following table:

| FPL Platform | FPL Code | Panel Model    | Marketing Name          | First Introduced |
| ------------ | -------- | -------------- | ----------------------- | ---------------- |
| 2.0          | 0        |                |                         | ?                |
| 2.1          | 1        |                |                         | 2004             |
| 2.3          | 2        |                |                         | ?                |
| V100         | 3        |                | Vizplex                 | 2007             |
| V110         | 4        |                | Vizplex                 | 2008             |
| V110A        | 5        |                | Vizplex                 | 2008             |
| V220         | 6        | VA3200         | Pearl                   | 2010             |
| V250         | 7        |                | Pearl                   | ?                |
| V220E        | 8        |                | Pearl                   | ?                |
| V320         | 9, R     | VB3300         | Carta 1.2 / 1000        | 2013             |
| V320         | ?        | VB3300?        | Carta 1100              | 2019             |
| V400         | A, C     | VD1400/ VD1405 | Roadrunner / Carta 1200 | 2021             |
| V450         | ?        | VH1948         | Carta 1250              | 2021?            |
| ?            | ?        | VD1400/ VD1405 | Carta 1300              | 2023             |
| ?            | M        | ?              | Spectra (BWR)           | ?                |

Data points used to create the table above:
- The first commercialized Eink e-reader SONY Librie hit the market in 2004, *likely* with an ED060SC1 panel
- ED060SC1 has an FPL code of 1 on the barcode, meaning the 2.1 platform
- Multiple datasheets (like the one for ED060SC4) confirms the 6th digit marks the FPL code with mapping for V220/220E/320/400
- Inkwave's WBF decoder (originated from Kindle GPL kernel code) provides an FPL platform to an FPL code mapping table that matches well with info from the datasheet
- Kindle Oasis3 was reported to use a Carta 1100 screen, and it has an ED070KC3 screen with a V320 FPL platform
- Kindle PW5 was reported to use a Carta 1200 screen, and it has an ED068KC5 with a VD1405 panel model
- Kobo Clara BW was reported to use a Carta 1300 screen, and it has an ED060KHE with a VD1405 panel model
- The datasheet of ED068KC1 mentioned the name "Roadrunner" for the 400 platform, but that name never gets used outside of that. I would guess they were going to use the Roadrunner for the new generation but eventually fell back to Carta 1200 so it's more like an incremental improvement
- From the information available, it really looks like Carta 1000 and 1100 use the same film, and Carta 1200 and 1300 use the same film. If this is true, it may sound like a scam if they are named differently but use the same film. But this is actually okay. Just like how chips usually have a binning process, the same chip would sell under different product names with different performance levels. It's reasonable for Eink to do incremental improvements on the manufacturing process to yield better screens with the same film and call it under a different name, or simply binning screens to different grades and selling under different names.

I will let you decide how to count the generations.

For the CFA-based screens, the following generations of screens exist:

- Eink Triton: First generation color screen. Uses an RGBW glass color filter and square pixels. The underlying screen panel uses Pearl film.
- Eink Triton 2: 2nd generation color screen. Uses RGB glass color filter and stripe pixel. The underlying screen panel uses Pearl film.
- Eink Kaleido: 3rd or 2nd gen color screen depending on the definition. Uses an RGB color filter. Each pixel is still square, but each color covers 3 pixels. The underlying screen panel uses Carta film.
- Eink Kaleido Plus: 2nd gen Kaleido. Uses an RGB color filter. Each pixel is still square but different configurations exist. Some screens have each color covering 2 pixels, some others have each color covering only 1 pixel. The underlying screen panel uses Carta film.
- Eink Kaleido 3: 3rd gen Kaleido. There are at least 2 different configurations exist. One features RGB filter covering 1 pixel per color, the other features a 2R/2G/1B configuration, on average 5/3 pixels per color. The underlying screen panel uses Carta 1000/1200/1250/1300 film depending on the model.
- Eink Kaleido 3 Outdoor: Wide temperature version of Kaleido 3.

Most CFA-based color screen panels don't come with an integrated controller, but there are a few exceptions.

For the multiple-pigment color screens based on SiPix technology, the following generations of screens exist:

(Color abbreviation: B: black, W: white, R: red, Y: yellow, B: blue, C: cyan, M: magenta)

- Eink Spectra 3000: BWR or BWY 3 color screen.
- Eink Spectra 3100: BWRY 4 color screen.
- Eink Spectra 3100 Plus: BWRY 4 color screen. The orange display is now possible with driver circuit changes.
- Eink Spectra 6: RYBW 4 color screen. Can reproduce 6 primary different colors. Newer waveforms released by Eink increased this number to 10.
- Eink Spectra 6 Plus: RYBW 4 color screen. Still reproduces 6 different colors. Allows faster refresh compared to 6 with driver circuit changes.
- Eink Gallery (also known as Gallery 4000): CMYW 4 color screen (ACeP).
- Eink Gallery Plus (also known as Gallery 4000): CMYW 4 color screen (ACeP).
- Eink Gallery Palette (also known as Gallery Palette 4000)： CMYW 4 color screen (ACeP). Reproduce 7 different colors.
- Eink Gallery 3: CMYW 4 color screen (ACeP). Reproduce 8 different colors, much faster than other Gallery screens at the cost of lower saturation.

There are both integrated-controller Spectra/Gallery screens and controller-less Spectra/Gallery screens.

Additional notes regarding the multi-pigment color screens:

- ACeP, or Advanced Color ePaper refers to the CMYW 4 color screen. Is not a product line on its own
- To be honest, I don't know how many colors can be reproduced on Gallery or Gallery Plus screens based on public information. The spec sheets for [AC133UT1](https://www.beck-elektronik.de/fileadmin/user_upload/Produkte/BECK_Elektronik/Displays/Downloads/EPD/E-Ink/AC133UT1_Specs.pdf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) suggests it might be 8 colors. Eink claims 32000 or 60000 colors in their materials, but they also clarified these numbers refer to color gamut. In other words, they represent color saturation rather than a number of different colors that can be displayed on screen. Dithering is heavily used to display color images on Gallery screens.
- It's possible to achieve more colors on Gallery Palette screens. 7 is not a physical limit.
- The Gallery 4000 rebranding happened in [2020](https://www.linkedin.com/pulse/e-ink-gallery-4000-anna-rybalko/) however Eink never seems to use that name on their website.

## Design of Caster and Glider

This section describes the design specific to the Caster and Glider. The following is an overall block diagram showing both hardware and gateware components in the signal chain:

![Overall ABlockdiagram](assets/glider_overall_block_diagram.svg)

### Gateware Architecture

The FPGA gateware is divided into multiple modules. The caster.v is the top-level of the EPDC core design, but several additional components are connected under top.v to form a complete image processing system. Different components are generally inter-connected with synchronous or asynchronous (in case of clock domain crossing) FIFOs.

The top-level design has 3 major clock domains: clk_vi: Input video clock domain, running at ½ pixel rate. clk_epdc: EPDC clock domain, running at ¼ pixel rate. clk_mem: Memory clock domain, running at ¼ memory transfer rate.

To understand how it works, the following is a guided tour around the life cycle of a pixel.

Before an incoming pixel can be processed by the controller, the memif module needs to retrieve the local pixel state from the DDR SDRAM. Once the value is retrieved, it’s pushed into the state readout/ input FIFO (bi_fifo). At/ around the same time, the input video stream is pushed into the video input FIFO (vi_fifo).

The EPDC runs a local Eink timing generator for counting pixels and blankings. This timing should be a slightly delayed version of the incoming video timing. Once the local timing generator determines that it needs to output the pixel soon, the EPDC logic pops out one pair of the video input and state readout and starts processing.
Two values go through the video processing pipeline:

- Stage 1: This pipeline stage waits for the FIFO to output the data.
- Stage 2: The 8-bit input image is dithered down to 1-bit and 4-bit at this stage for later use.
- Stage 3: The waveform lookup is done at this stage for 16-level grayscale modes
- Stage 4: Based on the pixel state, the new state and voltage selection value are determined at this stage.
- Stage 5: The new state is pushed into the state writeback/ out FIFO (bo_fifo) and the voltage selection is sent to the screen.

The memif module later pops out the writeback value from the bo_fifo and writes it back to the DDR SDRAM.

The EPDC always processes 4 pixels per clock. For screens with different interface widths, a rate adapter is added after the EPDC output. Some logic is duplicated 2 or 4 times (such as the waveform RAM or the pixel decision logic), while some are extended and daisy-chained (such as the error diffusion dithering unit) to achieve the 4 pixels per clock throughput.

### Firmware Functions

The MCU manages housekeeping items as described below. It uses FreeRTOS as the operating system.

- EPD power supply: The power supply provides a common, source, and gate supply to the EPD panel. In addition to a basic on/off switch, the MCU can also adjust the VCOM voltage, and measure the optimal VCOM voltage of the panel installed. The VCOM measurement is done by isolating the VCOM supply from the screen while keeping the gate supply, scanning the screen with source = VCOM, and measuring the kick-back voltage on the VCOM.
- Power supply monitoring: The microcontroller monitors voltage and current of different rails, and ensure they are in the expected range.
- FPGA bitstream loading: The FPGA doesn’t have its own flash memory, the bitstream is pushed over SPI from the MCU to the FPGA upon powering up. In this way, the FPGA bitstream can be easily bundled together with the MCU’s firmware and updated together.
- Type-C negotiation: The onboard USB Type-C port can support video input in addition to powering the board using the USB-C DisplayPort Alt Mode. The MCU runs a USB-C PD stack to communicate this capability to the video source device over standard USB PD protocol. The MCU also controls the Type-C signal mux to remap the lanes to the correct place depending on the cable orientation.
- Video decoder initialization: The FPGA used on the board doesn’t have high-speed deserializers to interface with common high-speed video interfaces such as DisplayPort or DVI directly. Instead, dedicated video decoder chips are used on the board. They typically need initialization before use, and the MCU takes care of this. In this specific design, the DP decoder chip also handles AUX P/N line flipping based on the Type-C cable orientation.
- PC communication: One advantage of the Caster is that update modes and forced update/ clearing can be applied on a per-pixel basis. Software may utilize this to assign different modes to different windows or change update modes depending on the content on the fly. This is done by sending requests to the MCU over a USB connection. The MCU runs TinyUSB and presents itself as an HID device so it can forward messages between the host PC and the FPGA.

### Low Latency Drive

The Caster implements several techniques for reducing the latency, which will be explained here.

As described before, the existing basic driving method employs a global counter for looking up the waveform table. This imposes a limit on the global image update rate: the controller only accepts a new incoming image after the previous update is finished. The update usually takes about 100ms, translating to an image rate of 10Hz. Or, in other words, the user needs to potentially wait up to 100ms before the new image is even processed by the controller.

One way to mitigate this issue is by having multiple update regions. For example, imagine the user is typing a and b. In a single region controller design, a is drawn to the screen immediately, while the b needs to wait 100ms before it gets drawn. If the controller supports multiple regions, it could start drawing the letter b as soon as it’s typed, reducing the latency. This however requires the software to program the controller to correctly set the region to the letter boundary, and re-allocating regions on the fly as the number of regions is generally quite limited (like 4-16).

![caster-pipelined](assets/caster_pipelined_update.svg)

The Caster simply treats every pixel as an individual update region, for maximum flexibility and is transparent to the software.

Another latency optimization technique the Caster implemented is on the pixel that’s already being updated. For example, if the user types the letter a and deletes it right after. With the basic driving method, the controller needs to wait till the letter a is fully displayed before it can erase it. The previously proposed/ implemented regional update doesn’t help here because in this situation it’s about the same pixel so it has to be in the same region. The second technique is early cancellation. If a pixel changes before it’s fully driven, instead of waiting for it to be fully driven, it’s driven toward the requested input state, and the frame counter is updated depending on the newly calculated driving time.

![caster-early-cancel](assets/caster_early_cancel.svg)

By combining both, it’s then possible to implement low-latency binary and 4-level grayscale modes. The tradeoff between framerate and contrast ratio is also no longer relevant. Both a high frame rate and high contrast ratio are achieved automatically.

### Hybrid Greyscale Mode

As discussed previously, getting [greyscale](#greyscale-display) image on Eink is a sophisticated process, much slower than binary, and shows flashing images during the process. This poses challenges on how to make it useful for the users.

On eReaders, the software could switch between fast and slow modes based on the action. The eReader software may also simply not support things that don’t work well on the screen. For example, there might be no scrolling but only whole page flipping. What’s being done on existing eink monitors is throwing the problem back to the user. The user simply needs to accept that the update is slow, the latency is long, and the process is flashing.

What Caster implemented is allowing it to switch between the fast binary mode and slow greyscale mode automatically on a per-pixel basis. When the input image is changed, it switches to binary mode and does the update. When the image hasn’t changed for a while, it re-renders the image in greyscale.

### Limitations

The method does come with downsides: it requires much more memory bandwidth to implement. Taking a 1080P panel as an example (roughly 120 Mp/s (million pixels per second) with reduced blanking). With the traditional method, the controller only needs the old pixel state and the new pixel state (4bpp each) to determine the voltage needed or 8-bit/ 1-byte memory read per pixel. The bandwidth requirement is then 120Mp/s x 1B/pixel = 120MB/s. One single 16-bit SDR-133 SDRAM is more than enough to handle this. The Caster currently stores a 16-bit state per pixel (for 2 sets of old pixel values and pixel-specific timer counters), and the pixel state needs to be updated per frame, so the pixel state buffer alone requires 2-byte read and 2-byte write per pixel. It then takes another 0.5-byte per pixel to read the new image value from memory. 120Mp/s x 4.5B/pixel = 540MB/s. A 16-bit DDR-333 memory is then needed to implement this. The Glider hardware uses a DDR3-800 memory to allow even higher resolution. If the controller is not integrated inside an SoC (like our case, the controller is sitting inside the monitor, not part of your PC’s CPU/GPU), it also needs to use actual low latency video interfaces like DVI or DP, instead of simpler but slower interfaces like USB or I80/SPI. This could drive up costs as well. These techniques also don't help with use cases like reading books, so commercial e-reader solutions have little reason to spend the extra trouble to implement these.

### Hardware Design Decisions

To be written (TODO)

### Resources Utilization

The following numbers are for reference only and would vary depending on RTL options and specific targets.

- 1704 FF
- 2531 LUT6
- 60 KB BRAM

## Building

### PCB

The PCB is designed with KiCAD 8.0. To get optimal results, use a 4-layer stack up with 1080 PP layers, but 2313 or 3313 are also acceptable.

### FPGA Bitstream

To build the FPGA bitstream:

#### Install Xilinx ISE 14.7

Xilinx ISE 14.7 is required for building bitstream of the FPGA. It no longer supports latest operating systems (officially only up to Windows 7), so there are 3 ways:

- Use the official RHEL virtual machine provided by Xilinx: the recommended way, should work on any modern OSes
- Use old operating system (such as Windows 7): Obvious way, but using deprecated OSes has its own implications
- Install the software anyways and find hacks to make it work: I have had luck get it running on Ubuntu 20.04, Windows 10, and Windows 11. Your mileage might vary.

The software is available for download at [https://www.xilinx.com/downloadNav/vivado-design-tools/archive-ise.html](https://www.xilinx.com/downloadNav/vivado-design-tools/archive-ise.html). The "ISE Design Suite for Windows 10 and Windows 11" is the official virtual machine. To use the virtual machine method, download this even if you are not on Windows 10/11. Otherwise, download the normal 14.7 version.

If you are using the virtual machine on platforms other than Windows 10/11, you can extract only the ova file from the zip file. The ova file can then be imported into software like VirtualBox. Note that the ISE inside the virtual machine uses the MAC address for verifying the license. Please make sure you don't change the MAC address for the NIC inside the virtual machine. (When importing, include all network adapter MAC addresses just to be sure.)

#### Clone Caster Repository

The FPGA gateware source code is hosted in a separate repository, and can be cloned by running:

```
git clone --recursive https://gitlab.com/zephray/Caster.git
```

Make sure to use the recursive flag to clone submodules as well.

#### Configuring Parameters

Most of the parameters are configured over the SPI bus from the MCU. However there are still some compile time parameters to be set before building the FPGA bitstream.

- In `rtl/spartan6/top.v`, there is a parameter called `COLORMODE`. It can be set to `MONO`, `RGBW`, or `DES`. `RGBW` should be used on OED panels, and `DES` should be used on Kaleido 3 and DES screens.
- In `rtl/defines.vh`, there is a define called `OUTPUT_16B`. Define this flag when using 16-bit panels.

Note that for both Modos kits (6" and 13"), default setting (MONO, 8-bit) is the correct setting.

#### Build FPGA Gateware using GUI

There are 2 ways to build the gateware. One is using Xilinx's ISE GUI, another is using build script. Note that on a freshly cloned repo, you will need to build with GUI at least once to re-generate all necessary IPs.

1. Open ISE Project Navigator
2. Click `Open Project...`, open `Caster/rtl/spartan6/caster.xise`
3. In the left processes pane, double click `Generate Programming File`
4. It would prompt about IP regeneration multiple times, click `Yes` every time
5. It should then build the bitstream. The output file is `rtl/spartan6/top.bit`

#### Build FPGA Gateware using script

1. Open a terminal
2. Change directory to `Caster/rtl/spartan6/par`
3. Run `build.sh` or `build.bat` depending on the OS to build the bitstream. The output file is `fpga.bit`

### MCU Firmware

To build the MCU firmware:

#### Install STM32CubeIDE

The software is freely available on ST's website: [https://www.st.com/en/development-tools/stm32cubeide.html](https://www.st.com/en/development-tools/stm32cubeide.html). It supports all 3 major operating systems.

#### Clone Glider Repository

The repository can be cloned by doing:

```
git clone --recursive https://gitlab.com/zephray/Glider.git
```

Make sure to use the recursive flag to clone submodules as well.

#### Build MCU firmware

1. Open STM32CubeIDE, launch with any workspace path (default is fine)
2. In the menu, click `File` -> `Open projects from file systems`
3. Click `Directory...` button and select `Glider/fw`, click `Open`
4. It should scan the folder and recognize it as a project, click `Finish`
5. In the `Project Explorer` pane on the left, click the `glider_ec_rtos` project to highlight it
6. Click the build icon in the toolbar (or in the menu, `Project` -> `Build Project`)
7. It should build correctly. If it complaines about missing tusb.h, it means the submodule wasn't cloned (probably because the `--recursive` flag was missing or it was downloaded from the webpage). The output is `Glider/fw/Debug/glider_ec_rtos.bin`

### Flashing Board

To flash the firmware:

- Install dfu-util (for example, `apt install dfu-util`, or `brew install dfu-util`)
- Holding the button closer to the USB port and plug in the USB cable
- Use one of the 2 methods to complete the flashing process

#### Method 1: Use the provided flashing tool

- Make sure you have a Python 3 environment and you can install packages to it
- Install `hidapi` Python package by running `pip3 install hidapi`
- Change directory into `utils/flash_tool` and copy over compiled bitstream `fpga.bit` and firmware `glider_ec_rtos.bin`
- Run the tool `python3 flash.py`

#### Method 2: Manual flashing

- Run `sudo dfu-util -l`, it should detect 2 DFU devices
- Run `sudo dfu-util -a 0 -i 0 -s 0x08000000:leave -D glider_ec_rtos.bin`
- It should show `File downloaded successfully`
- Unplug and plug in the USB cable again to reboot to the new firmware
- The board should be detected as an USB serial device (check /dev/tty*, on macOS it's something like /dev/tty.usbmodem310038002, on Linux probably /dev/ttyACM0)
- Use a serial terminal to connect to the board (I recommend use minicom for Linux, coolterm for macOS, and Tera Term for Windows)
-  Now you should be in Glider's shell. Pressing enter should show a "#" prompt. Run the `ver` command, it should report the new build date time.- Now use the shell to update the bitstream for fpga. Enter command  `recv fpga.bit` in the shell (recv is the command for receiving file over XMODEM protocol, 'fpga.bit' is the filename to save as. It would be saved to the on-board flash)
- After that, the board would start waiting for file transmission. In minicom, Press Meta-S (Ctrl-A then S on Linux) to open the upload menu. Select xmodem then select the top.bit file to transmit it. It might take up to 2 seconds to establish the transfer. There is a 10s timeout after which the board stops trying to receive the file. Just run the recv command again to retry if that happens. In other software, similarly use Xmodem transfer feature to send the file
- After the bitstream is transferred, firmware upgrade is finished
- If this is a fresh install, transfer over the font file (font_24x40.bin) using the same method as the bitstream

### Compatible Screens

The Modos Dev Kit offers two screen options: 13.3" 1600x1200 and 6" 1404x1072. However the board is capable of driving other panels as well. See [Screen Panels](#screen-panels) for differences between different types of screen panels available.

#### Screen Adapters

Different screen panels have different connectors. It would take a huge amount of space to have every possible screen connector on the motherboard. Instead, a series of different screen adapters are provided to adapt to the screen with different pinouts.

The motherboard uses a 50pin + 16pin connector. A single 50pin connector is enough for 8/16-bit screens, the 16 pin connector additionally adds support for LVDS screens and 32-bit/ 64-bit screens.

Mega adapter 1: Most common screens

- 33P-A: ED097OC1-4/TC1
- 34P-A: ED060XC3/XD4/XG1 etc.
- 39P-A: ED133UT1-3 ED050SU3 etc.
- 40P-A/B: ED078KC1 ED103TC2 etc. (A inserts with contact facing down, B inserts with contact facing up)
- 50P-A: ED113TC1

To see which adapter might work for your screen, check out the [Appendix 1 - Screen List](#screen-list)

#### Pixel Rate Considerations

The input protocol and processing rate limit the screen model supported.

Limit from processing rate (logic and routing delay):

* Processing rate when dithering enabled: 133 MP/s
* Processing rate when dithering disabled: 280 MP/s
* Estimated processing rate with 8-wide design: 500 MP/s

Limit from video interface:

* Maximum pixel rate using DVI (with ADV7611): 165 MP/s
* Maximum pixel rate using DVI (direct deserializer): 105 MP/s
* Maximum pixel rate using DisplayPort (with PTN3460): 224 MP/s
* Maximum pixel rate using DisplayPort (with 7-series 6G SerDes): 720 MP/s
* Maximum pixel rate using MIPI (with 1.05Gbps LVDS): 230 MP/s

Limit from memory interface (assuming 90% BW utilization):

* SDR-166 x16: 60 MP/s
* SDR-166 x32: 120 MP/s
* DDR-400 x16: 180 MP/s
* DDR2/3-667 x16: 300 MP/s
* DDR2/3-800 x16: 360 MP/s
* DDR2/3-1066 x16: 480 MP/s
* DDR2/3-800 x32: 720 MP/s

Common screen resolution peak pixel rate (with CVT-RBv2):

* 1024x758 (6.0") @ 85Hz: 74 MP/s
* 1448x1072 (6.0") @ 60Hz: 101 MP/s
* 1448x1072 (6.0") @ 85Hz: 145 MP/s
* 1600x1200 (13.3") @ 60Hz: 125 MP/s
* 1600x1200 (13.3") @ 85Hz: 178 MP/s
* 1872x1404 (10.3") @ 60Hz: 169 MP/s
* 1872x1404 (10.3") @ 85Hz: 243 MP/s
* 1920x1440 (8.0") @ 60Hz: 177 MP/s
* 1920x1440 (8.0") @ 85Hz: 255 MP/s
* 2200x1650 (13.3") @ 60Hz: 232 MP/s
* 2200x1650 (13.3") @ 85Hz: 333 MP/s
* 2560x1600 (12.0") @ 60Hz: 261 MP/s
* 2560x1600 (12.0") @ 85Hz: 374 MP/s
* 2560x1920 (13.3") @ 60Hz: 313 MP/s
* 2560x1920 (13.3") @ 85Hz: 449 MP/s
* 3200x1800 (25.3") @ 60Hz: 364 MP/s
* 3200x1800 (25.3") @ 85Hz: 522 MP/s

( Calculate yourself: [Video Timings Calculator by Tom Verbeure](https://tomverbeure.github.io/video_timings_calculator) )

Rendering the grayscale requires the screen to be refreshed at 85Hz (85Hz is the supported refresh rate by Eink, 60Hz can be made to work with some effort in some cases). Running an input refresh rate lower than the internal refresh rate incurs additional processing latency from both source (PC) and monitor due to buffering.

#### Setting Configurations

The board won't be able to automatically detect the resolution of connected screen. It need to be set manually through boards' shell. Here is a general guide for calculating these values.

First, use the [video_timings_calculator](https://tomverbeure.github.io/video_timings_calculator) to calculate host timings. Enter the resolution and desired refresh rate in the calculator. Note the pixel clock cannot exceed 165MHz. If the result is higher than 165MHz, lower the refresh rate.

Current version of the Caster has additional requirements of the resoltion: X resolution multiply by Y resolution must be a multiple of 128. This limitation means certain screens won't be able to display the full image/ utilize the full panel.

Using 13.3" 220ppi screen with a resolution of 2200x1650 as an example. Notice that 2200x1650 is not a multiple of 128. Here I choose 2200x1648 as a compromise, leaving the last 2 lines unused. Enter the value 2200 into horizontal pixels, and 1648 into vertical pixels. It provides several standards to choose from, for most screens we can just use CVT-RBv2 for lowest pixel clock. Notice that in this case, the calculated pixel clock is 231.876MHz at 60Hz, which is higher than 165MHz. So the refresh rate has to decreased to 42Hz for a pixel clock of 160.972MHz. Now we have our first set of parameters:

```
pclk_hz (Pixel Clock) = 160972000
hfp (H Front Porch) = 8
hsync (H Sync) = 32
hblk (H Blank) = 80
hact (H Active) = 2200
vfp (V Front Porch) = 19
vsync (V Sync) = 8
vblk (V Blank) = 33
vact (V Active) = 1648
```

Next on to TCON (timing controller) parameters. For the vertical timings,

- tcon_vact is equal to vact, which is 1650 in this case
- tcon_vsync is generally set to 1
- tcon_vbp is generally set to 2, or 1 is mirroring is used (It depends on the screen used. If the image is vertically shifted, adjust this value.)
- tcon_vfp is equal to vblk - vfp - tcon_vsync - tcon_vbp, which is 33 - 19 - 1 - 2 =  11 in this case
- tcon_hact is equal to hact divide by 4, which is 2200 / 4 = 550 in this case
- tcon_hsync is generally set to 2
- tcon_hbp is generally 2 (It depends on the screen used. If the image is horizontally shifted for a few pixels, adjust this value)
- tcon_hfp is euqal to hblk / 4 - tcon_hsync - tcon_hbp, which is 80 / 4 - 2 - 2 = 16 in this case 

The VCOM voltage should be somewhere on your screen. It's generally a negative voltage between -3V to 0V. The board is capable of outputting voltage from -2.67V to -0.01V.

Finally, using setcfg command to save these settings to the board:

```
setcfg set pclk_hz 160972000
setcfg set hfp 8
setcfg set hsync 32
setcfg set hblk 80
setcfg set hact 2200
setcfg set vfp 19
setcfg set vsync 8
setcfg set vblk 33
setcfg set vact 1650
setcfg set vcom -1.26
setcfg set tcon_vact 1648
setcfg set tcon_vsync 1
setcfg set tcon_vbp 2
setcfg set tcon_vfp 11
setcfg set tcon_hact 550
setcfg set tcon_hsync 2
setcfg set tcon_hbp 2
setcfg set tcon_hfp 16
setcfg save
```

## References

Here is a list of helpful references related to driving EPDs:

* Reverse engineering and explanation on driving EPDs: http://essentialscrap.com/eink/index.html
* An early Eink DIY project with many useful info: http://spritesmods.com/?art=einkdisplay&page=1
* STM32 Software bit-banging EPD driver with grayscale: https://hackaday.io/project/11537-nekocal-an-e-ink-calendar
* ESP32 board designed for driving parallel EPDs: https://github.com/vroland/epdiy
* An early tool for reading Eink's wbf file format: https://github.com/fread-ink/inkwave
* A more up-to-date Eink's wbf format parser: https://patchwork.kernel.org/project/linux-arm-kernel/patch/20220413221916.50995-2-samuel@sholland.org/

On the topic of color screen resolution, color mapping, and subpixel rendering:

* Klompenhouwer, Michiel A., and Erno H. A. Langendijk. “59.4: Comparing the Effective Resolution of Various RGB Subpixel Layouts.” SID International Symposium Digest of Technical Papers, vol. 39, no. 1, 2008, pp. 907–10, https://doi.org/10.1889/1.3069822.
* Lai, Chih-chang, and Ching-chih Tsai. “A Modified Stripe-RGBW TFT-LCD with Image-Processing Engine for Mobile Phone Displays.” IEEE Transactions on Consumer Electronics, vol. 53, no. 4, 2007, pp. 1628–33, https://doi.org/10.1109/TCE.2007.4429262.

## License

This document, other than references explicitly given with their corresponding license, is released into the public domain.

The hardware design is released under the CERN Open Source Hardware License strongly-reciprocal variant, CERN-OHL-S. A copy of the license is provided in the source repository. Additionally, a user guide of the license is provided on ohwr.org.

The firmware code is licensed under the MIT license with the following exceptions:

The USB PD library is derived from the Chromium OS project and the reclamier labs. The library is licensed under the BSD license.

## Appendix

### Using Screens without Datasheet

To be written

### Screen List

This is a list of Eink screens their key parameters and their compatibilities with Caster/ Glider. **This is a list of all E-ink screens that have public information available, not a list of screens that's compatible with the Glider.** The information is gathered from public sources, so they might be incorrect. This is not a complete list of all screens Eink has ever produced or is in production. This table is intended for hobbyists buying used screens. If you are designing a product with Eink screen please contact Eink directly.

Other than a few exceptions, only screens without integrated TCON are listed here (in other words, SPI screens are generally not included here). These screens are the main focus of this project anyway.

Screen size is the first 3 numbers in the model number, so it's not listed separately in the table. For example, ED060SC4 is 6.0", ED097OC1 is 9.7", and ES133UT1 is 13.3".

First 2 letters denotes the screen type:

- ED: Glass monochrome
- EC: Glass CFA-based color
- ES: Flexible monochrome (new)
- ET: Flexible monochrome (old)
- EQ: Flexible CFA-based color
- EL: Spectra series BWR/BWYR/RYBW color
- AC: ACeP CMYW color

The adapter column refers to the adapter needed for this particular screen. However, there is no guarantee that it would work, even if it's listed as tested.

| Model Name | Model Number | SN Initial | FPL Platform | Resolution  | Marketing Name              | R Typ | CR Typ | Year  | Interface | Pin Count | Adapter | Tested? |
| ---------- | ------------ | ---------- | ------------ | ----------- | --------------------------- | ----- | ------ | ----- | --------- | --------- | ------- | ------- |
| ET040TC1   |              | EBC        |              | 720x480     | Pearl                       |       |        | <2014 | TTL       |           |         |         |
| ED038TH1   |              | EKD        | V320         | 600x600     | Carta                       | 45%   | 17:1   | 2015  | TTL       | 34        | 34P-A   |         |
| ET040TC2   |              |            |              | 720x480     | Pearl                       |       |        |       | TTL       |           |         |         |
| ET040TC3   |              | EMA        |              | 720x480     | Pearl                       |       |        | <2019 | TTL       | 40        |         |         |
| ED043WC1   |              | E8N        | V220         | 800x480     | Pearl                       | 35%   | 12:1   | 2013  | TTL       | 39        | 39P-C   |         |
| ED043WC3   | VA3200-DCA   | EE7        | V220         | 800x480     | Pearl                       |       |        | 2014  | TTL       | 39        | 39P-C   |         |
| ED043WC5   | VD1405-CGA   |            | 400          | 800x480     | Carta 1200                  |       |        |       | SPI       |           |         |         |
| ED043WH1   |              | EA7        | V220         |             | Pearl                       |       |        | <2014 | TTL       | 40        |         |         |
| ED047TC1   |              | EDV/W      | V220         | 960x540     | Pearl                       | 35%   | 12:1   | 2015  | TTL       | 44        |         |         |
| ED047TC2   |              | EG8        | V220         | 960x540     | Pearl                       | 35%   | 12:1   | 2016  | TTL       | 40        |         |         |
| ET047TC1   |              | EBL        | 320          | 960x540     | Carta 1.2                   |       |        | <2015 | TTL       |           |         |         |
| ET047TC2   |              | EF5        | 320          | 960x540     | Carta 1.2                   |       |        | <2015 | TTL       |           |         |         |
| ED050SC3   |              | E0Y/1N/7Y  | V110         | 800x600     | Vizplex                     | 35%   | \>6:1  | 2008  | TTL       | 33        | 33P-A   |         |
| ED050SC5   |              | E7V        | V100/V220    | 800x600     | Vizplex / Pearl             |       |        |       | TTL       |           |         |         |
| ED050SU1   |              | E0W        | V110         | 800x600     | Vizplex                     |       |        |       | TTL       |           |         |         |
| ED050SU2   |              | E1G        | V110         | 800x600     | Vizplex                     |       |        | <2009 | TTL       |           |         |         |
| ED050SU3   |              | E2U        | V220E        | 800x600     | Pearl                       |       |        | <2010 | TTL       | 39        | 39P-A   | Yes     |
| ED052TC2   |              |            | 320          | 960x540     | Carta                       | 45%   | 16:1   | 2016  | TTL       | 40        |         |         |
| ED052TC4   | VB3300-EBA   | ENB        | 320          | 1280x720    | Carta 1.2                   | 45%   | 16:1   | 2017  | TTL       | 50        |         |         |
| EC058TC1   | SA1452-EHA   |            | 320          | 1440x720    | Kaleido / Carta             | 24%   | 15:1   | 2020  | TTL       | 50        |         |         |
| ED058TC7   |              |            | 320          |             | Carta                       |       |        |       | TTL       |           |         |         |
| ED058TC8   | VB3300-EHB   |            | 320          | 1440x720    | Carta                       |       |        |       | TTL       |           |         |         |
| ED060SC1   |              |            | 2.1          | 800x600     |                             |       |        |       | TTL       | 39        | 39P-B   |         |
| ED060SC3   |              |            | V100         | 800x600     | Vizplex                     |       |        | <2010 | TTL       | 39        | 39P-B   |         |
| ED060SC4   |              | E0R/1M/X   | V110         | 800x600     | Vizplex                     | 35%   | \>6:1  | 2008  | TTL       | 39        | 39P-B   |         |
| ED060SC7   |              | E2N/30/1/2 | V220E        | 800x600     | Pearl                       | 40%   | 12:1   | 2010  | TTL       | 34        | 34P-B   |         |
| ED060SCA   |              | E3D        | V110         | 800x600     | Vizplex                     |       |        | <2010 | TTL       |           |         |         |
| ED060SCE   |              |            | V220/V220E   | 800x600     | Pearl                       |       |        |       | TTL       | 34        | 34P-B   |         |
| ED060SCF   |              |            | V220         | 800x600     | Pearl                       |       |        |       | TTL       | 34        | 34P-A   |         |
| ED060SCG   |              |            | V220E        | 800x600     | Pearl                       |       |        |       | TTL       | 34        | 34P-B   |         |
| ED060SCN   |              |            | V220E        | 800x600     | Pearl                       |       |        |       | TTL       | 34        | 34P-A   |         |
| ED060SCS   |              | EHB        | V220         | 800x600     | Pearl                       |       |        |       | TTL       | 34        | 34P-B   |         |
| ED060SCP   |              |            | V220         | 800x600     | Pearl                       | 40%   | 12:1   | 2014  | TTL       | 34        | 34P-A   |         |
| ED060SCQ   |              |            | V220         | 800x600     | Pearl                       |       |        |       | TTL       |           |         |         |
| ED060SCS   |              |            |              | 800x600     |                             |       |        |       | TTL       |           |         |         |
| ED060SCT   |              |            | 320          | 800x600     | Carta                       |       |        |       | TTL       | 34        | 34P-B   |         |
| ED060SD1   |              |            | 320          | 800x600     | Carta                       |       |        |       | TTL       |           |         |         |
| ED060SH2   |              |            | 320          | 800x600     | Carta                       |       |        |       | TTL       | 35        |         |         |
| ED060XC3   |              |            | V220         | 1024x758    | Pearl                       |       |        |       | TTL       | 34        | 34P-A   | Yes     |
| ED060XC5   |              | E61        | V220         | 1024x758    | Pearl                       | 35%   | 12:1   | 2011  | TTL       | 34        | 34P-A   |         |
| ED060XC8   |              |            | V320         | 1024x758    | Carta                       |       |        |       | TTL       | 35        | 35P-A   | Yes     |
| ED060XC9   |              |            |              | 1024x758    |                             |       |        |       | TTL       | 34        | 34P-A   |         |
| ED060XCA   |              | EEG        |              | 1024x758    | Spectra 3000                |       |        | <2014 | TTL       | 34        | 34P-A   |         |
| ED060XCD   |              |            | 320          | 1024x758    | Carta                       |       |        |       | TTL       |           |         |         |
| ED060XCG   | VD1405-FOA   | EX0        | 320/400      | 1024x758    | Carta 1000 / 1200           | 40%   | 17:1   | 2020  | TTL       |           |         |         |
| ED060XCH   | VD1405-FOE   | H3E        | 400          | 1024x758    | Carta 1200                  |       |        | <2024 | TTL       |           |         |         |
| ED060XD4   |              |            | 320          | 1024x758    | Carta                       |       |        |       | TTL       | 34        | 34P-A   | Yes     |
| ED060XD6   |              |            |              | 1024x758    |                             |       |        |       | TTL       | 34        | 34P-A   |         |
| ED060XG1   |              | E7B/G      | V110/V220    | 1024x758    | Vizplex / Pearl             | 40%   | 12:1   | 2012  | TTL       |           |         |         |
| ED060XG2   |              |            | V220         | 1024x758    | Pearl                       |       |        |       | TTL       |           |         |         |
| ED060XG3   |              |            | 320          | 1024x758    | Carta                       |       |        |       | TTL       |           |         |         |
| ED060XH2   |              |            |              | 1024x758    |                             |       |        |       | TTL       | 34        | 34P-A   |         |
| ED060XH7   |              |            | 320          | 1024x758    | Carta 1.2                   | 45%   | 17:1   | 2015  | TTL       |           |         |         |
| ED060XH9   | VB3300-FOG   | EX4        | 320          | 1024x758    | Carta                       |       |        | <2023 | TTL       |           |         |         |
| ED060TC1   |              |            | 320          | 1448x1072   | Carta                       |       |        |       | TTL       | 35        | 35P-A   |         |
| EN060TC1   |              | EDG        | 320          | 1448x1072   | Carta                       |       |        | <2016 | TTL       |           |         |         |
| ED060KC1   |              | ECV/X/LY   | 320          | 1448x1072   | Carta                       | 46%   | 17:1   | 2014  | TTL       | 34        | 34P-A   |         |
| ED060KC4   |              |            | 320          | 1448x1072   | Carta                       |       |        |       | TTL       |           |         |         |
| ED060KD1   |              | EGS/NT     | 320          | 1448x1072   | Carta                       |       |        | <2017 | TTL       | 34        | 34P-A   | Yes     |
| ED060KG1   |              | EDJ/R      | 320          | 1448x1072   | Carta                       | 47%   | 17:1   | 2015  | TTL       | 34        | 34P-A   |         |
| ED060KH4   |              |            | 320          | 1448x1072   | Carta                       |       |        |       | TTL       |           |         |         |
| ED060KH5   |              | EGT        | 320          | 1448x1072   | Carta                       |       |        |       | TTL       |           |         |         |
| ED060KH6   | VB3300-FOE   | ER8/M      | 320          | 1448x1072   | Carta                       |       |        |       | TTL       |           |         |         |
| ED060KHA   | VB3300-FOJ   | H4A        | 320          | 1448x1072   | Carta                       |       |        |       | TTL       |           |         |         |
| ED060KHC   | VD1405-FOD   | H3J        | 400          | 1448x1072   | Carta 1200                  |       |        | <2022 | TTL       |           |         |         |
| ED060KHE   | VD1405-FOH   |            |              | 1448x1072   | Carta 1300                  |       |        |       | TTL       | 34        | 34P-A   |         |
| EC060KH1   | SA1452-FOA   | EVB        |              | 1448x1072   | Kaleido                     | 20%   | 16:1   | 2019  | TTL       | 34        | 34P-A   |         |
| EC060KH3   | SC1452-FOA   | EYW        |              | 1448x1072   | Kaleido Plus                | 20%   | 14:1   | 2021  | TTL       | 34        | 34P-A   |         |
| EC060KH5   | SC1452-FOD   |            |              | 1448x1072   | Kaleido 3                   |       |        |       | TTL       | 34        | 34P-A   |         |
| ED061KC1   | VD1405-FAA   |            | 400          | 1648x824    | Carta 1200                  |       |        |       | TTL       |           |         |         |
| ED067KC1   | VB3300-FGA   | EWY        | 320          | 1800x900    | Carta                       | 45%   | 16:1   | 2020  | TTL       | 50        | 50P-B   |         |
| EC067KC1   | SA1452-FGA   |            |              | 1800x900    | Kaleido                     |       |        |       | TTL       | 50        | 50P-B   |         |
| ED068OG1   |              | E7M        | V220         | 1440x1080   | Pearl                       |       |        | <2013 | TTL       | 40        |         |         |
| ED068TG1   |              |            | 320          | 1440x1080   | Carta                       |       |        | <2013 | TTL       |           |         |         |
| ED068TG2   |              | ELH        | 320          |             | Carta                       |       |        | <2016 | TTL       |           |         |         |
| ED068TH1   |              |            | 320          | 1440x1080   | Carta                       |       |        | <2014 | TTL       |           |         |         |
| ED068TH3   | VB3300-FHA   | ESN        | 320          | 1440x1080   | Carta                       |       |        | <2022 | TTL       |           |         |         |
| ED068KC1   |              | EUU/S/V    | 400SU        | 1648x1236   | Carta 1200                  |       |        |       | TTL       | 40        |         |         |
| ED068KC3   | VD1405-FHD   |            | 400          | 1648x1236   | Carta 1200                  |       |        |       | TTL       | 40        |         |         |
| ED068KC5   | VD1405-FHF   | EXS/YC     | 400          | 1648x1236   | Carta 1200                  | \>44% | \>19:1 |       | TTL       | 40        |         |         |
| ET068SC1   |              | EMF        |              | 800x600     | Thin Pearl                  |       | 14:1   | 2018  | TTL       |           |         |         |
| ED070KC2   |              | ELF        | 320          | 1680x1264   | Carta 1100                  | \>47% | \>16:1 |       | TTL       |           |         |         |
| ED070KC3   |              |            | 320          | 1680x1264   | Carta 1100                  |       |        |       | TTL       |           |         |         |
| ED070KC4   | VD1400-GOC   |            | 400          | 1680x1264   | Carta 1200                  |       |        |       | TTL       |           |         |         |
| ED070KC5   |              | HCL        |              |             |                             |       |        | <2025 | TTL       |           |         |         |
| ED070KH1   |              |            | 320          | 1680x1264   | Carta 1100                  |       |        |       | TTL       |           |         |         |
| EC070KH1   | SC1452-GOA   |            |              | 1680x1264   | Kaleido Plus                |       |        |       | TTL       |           |         |         |
| EC070KH2   | SC1452-GOC   |            |              |             |                             |       |        |       | TTL       | 45        |         |         |
| LB071WS1   |              |            |              | 1024x600    |                             |       | 7:1    |       | TTL       |           |         |         |
| EC071KC2   | SC1452-GAB   |            |              | 1680x1264   | Kaleido 3 + IGZO            |       |        | 2024? |           | 60        |         |         |
| ET073TC1   |              | ELN        | V320         | 750x200     | Carta                       |       |        | 2016  | TTL       |           |         |         |
| ED078KC1   |              |            |              | 1872x1404   | Carta 1.2                   | 45%   | 16:1   | 2016  | TTL       | 40        | 40P-A   |         |
| ED078KC2   | VB3300-GHC   | ERJ        | 320          | 1872x1404   | Carta                       |       |        |       | TTL       | 40        | 40P-A   |         |
| ED078KH1   |              |            | 320          | 1872x1404   | Carta                       |       |        |       | TTL       | 40        | 40P-A   |         |
| ED078KH3   |              |            | 320          | 1872x1404   | Carta 1.2                   |       |        |       | TTL       | 40        | 40P-A   |         |
| ED078KH4   | VB3300-GHB   |            | 320          | 1872x1404   | Carta                       |       |        |       | TTL       | 40        | 40P-A   |         |
| ES078KC3   |              | EQN        | 320          |             | Carta                       |       |        | <2017 | TTL       | 60        |         |         |
| EC078KH3   | SC1452-GHA   |            |              | 1872x1404   | Kaleido Plus                |       |        |       | TTL       | 40        | 40P-A   |         |
| EC078KH4   | SC1452-GHB   |            |              | 1872x1404   | Kaleido Plus ?              |       |        |       | TTL       | 40        | 40P-A   |         |
| EC078KH5   | SC1452-GHC   |            |              | 1872x1404   | Kaleido Plus ?              |       |        |       | TTL       | 40        | 40P-A   |         |
| EC078KH6   | SC1452-GHD   |            |              | 1872x1404   | Kaleido 3                   |       |        |       | TTL       | 40        | 40P-A   |         |
| EC078KH7   | SC1452-GHE   |            |              | 1872x1404   | Kaleido 3                   |       |        |       | TTL       | 40        | 40P-A   |         |
| ED080XC1   |              |            | V110         | 1024x768    | Vizplex                     |       |        |       | TTL       |           |         |         |
| ED080TC1   |              | EBH        | V220         | 1600x1200   | Pearl                       |       |        | <2014 | TTL       | 40        | 40P-A   | Yes     |
| EC080SC2   |              | E9J        | V250         | 600xRGBx800 | Triton 2                    |       |        | <2013 | TTL       | 40        | 40P-A   | Yes     |
| ES080KC2   | VD1400-HOB   |            | 400          | 1920x1440   | Carta 1200                  |       |        |       | TTL       |           |         |         |
| ES080KH1   |              |            |              |             |                             |       |        |       |           |           |         |         |
| AC080KH1   | AD1004-HOA   |            | HAL3         | 1920x1440   | Gallery 3 + IGZO            |       |        |       | MiniLVDS  | 40x2      |         |         |
| AC080KH2   | AD1004-HOB   |            | HAL3         | 1920x1440   | Gallery 3 + IGZO            | 31%   | 9:1    | 2022  | MiniLVDS  | 40x2      |         |         |
| ED097OC1   |              |            | V110A        | 1200x825    | Vizplex                     | 35%   | 7:1    | 2008  | TTL       | 33        | 33P-A   |         |
| ED097OC4   |              | E35        | V110A/V220   | 1200x825    | Vizplex / Pearl             |       |        |       | TTL       | 33        | 33P-A   |         |
| ED097OD2   |              |            | V220         | 1200x825    | Pearl                       |       |        |       | TTL       | 33        | 33P-A   |         |
| ED097TC1   |              |            | V220         | 1200x825    | Pearl                       |       |        |       | TTL       | 33        | 33P-A   |         |
| ED097TC2   | VB3300-JGA   |            | 320          | 1200x825    | Carta 1.2                   | 42%   | 16:1   | 2016  | TTL       | 33        | 33P-A   |         |
| EC097SC3   |              |            | V250         | 1600x1200   | Triton                      |       |        |       | TTL       | 40        |         |         |
| EL097TR2   | EA2220-JGB   |            |              | 1200x825    | Spectra 3000                |       |        |       | TTL       |           |         |         |
| ED100UC1   | VB3300-KOA   | EUT        | 320          | 1600x1200   | Carta                       | 45%   | 16:1   | 2020  | TTL       | 40        | DIRECT  | Yes     |
| ES103TC1   | VB3300-KCA   | EKQ        | 320          | 1872x1404   | Carta 1.2                   | 40%   | 12:1   | 2016  | TTL       | 40        | DIRECT  |         |
| ED103TC2   | VB3300-KCD   |            | 320          | 1872x1404   | Carta                       | 43%   | 14:1   | 2019  | TTL       | 40        | DIRECT  |         |
| ES103TD1   |              |            | 320          | 1872x1404   | Carta                       |       |        |       | TTL       |           |         |         |
| ES103TD3   |              |            | 320          | 1872x1404   | Carta                       |       |        |       | TTL       |           |         |         |
| ES103TD6   | VH1948-KCA   |            | 450          |             | Carta 1250                  |       |        |       | TTL       | 45        |         |         |
| EC103TD1   | SA1452-KCC   |            |              | 1872x1404   | Kaleido                     |       |        |       | TTL       |           |         |         |
| EC103TH2   | SC1452-KCB   |            |              | 1872x1404   | Kaleido 3 ?                 |       |        |       | TTL       |           |         |         |
| ED103KC1   | VD1400-KCF   |            | 400          | 2480x1860   | Carta 1200                  |       |        |       | TTL       | 61        |         |         |
| EC103KH2   | SC1452-KCD   |            |              | 2480x1860   | Kaleido 3                   |       |        |       | TTL       |           |         |         |
| ES107KC1   | VD1400-KGA   | H4X        | 400          | 2560x1920   | Carta 1300                  |       |        |       | TTL       |           |         |         |
| ES108FC1   |              | EQG        | 320          | 1920x1080   | Carta                       | 46%   | 16:1   | 2017  | TTL       | 50        | 50P-C   |         |
| ES108FC2   | VB3300-KHB   | ESS        | 320          | 1920x1080   | Carta                       |       |        |       | TTL       |           |         |         |
| ED113TC1   | VB3300-LCA   | EQA        | 320          | 2400x1034   | Carta                       | 35%   | 12:1   | 2017  | TTL       | 50        | 50P-A   |         |
| ED113TC2   | VB3300-LCB   |            | 320          | 2400x1034   | Carta 1.2                   | 35%   | 12:1   | 2019  | TTL       | 50        | 50P-A   |         |
| EC113TC1   | SC1452-LCA   |            |              | 2400x1034   | Kaleido Plus ?              |       |        |       | TTL       | 50        | 50P-A   |         |
| ED115OC1   |              | E4R        | V220         | 2760x2070   | Pearl                       | 35%   | 12:1   | 2012  | TTL       | 40        | 40P-A   | Yes     |
| AC118TC1   | AD1004-LHA   | C0F        | HAL3         | 2160x1620   | Gallery 3 + IGZO            |       |        | <2021 | MiniLVDS  | 40x2      |         |         |
| ES120MC1   | VD1400-MOA   |            | 400          | 2560x1600   | Carta 1200                  |       |        |       | TTL       | 40        |         |         |
| ES133UT1   |              | E7S        | V220         | 1600x1200   | Pearl                       | 35%   | 12:1   | 2013  | TTL       | 39        | 39P-A   | Yes     |
| ES133UT2   |              | EM1        | 320          | 1600x1200   | Carta                       |       |        | <2017 | TTL       | 39        | 39P-A   | Yes     |
| ES133UE2   |              |            | 320          | 1600x1200   | Carta                       |       |        |       | TTL       | 39        | 39P-A   |         |
| ED133UT2   | VB3300-NCB   |            | 320          | 1600x1200   | Carta 1.2                   | 45%   | 16:1   | 2016  | TTL       | 39        | 39P-A   |         |
| ED133UT3   | VB3300-NCC   | ET4        | 320          | 1600x1200   | Carta                       | 45%   | 16:1   | 2019  | TTL       | 39        | 39P-A   | Yes     |
| ES133TT1   |              | EKV        | 320          | 2200x1650   | Carta                       |       |        |       | TTL       |           |         |         |
| ES133TT3   |              |            | 320          | 2200x1650   | Carta 1.2                   | 40%   | 12:1   | 2016  | TTL       | 39        |         |         |
| ES133TEB   | VH1948-NCA   | EWN        | 450          | 2200x1650   | Carta 1250                  |       |        | <2023 | TTL       | 45        |         |         |
| ES133TT5   | VH1948-NCC   | EXW        | 450          | 2200x1650   | Carta 1250                  |       |        | <2021 | TTL       | 45        |         |         |
| EC133UJ1   | SD1452-NCB   | H60        |              | 1600x1200   | Kaleido 3 Outdoor           |       |        | <2024 | TTL       | 39        | 39P-A   | Yes     |
| EQ133ME1   | SC1452-NCC   | H94        |              | 2200x1650   | Kaleido 3                   |       |        | <2024 | TTL       | 45        |         |         |
| EQ133ME2   | SC1452-NCD   | HAD        |              | 2200x1650   | Kaleido 3                   |       |        | <2024 | TTL       | 45        |         |         |
| ED133KC1   | VD1400-NCC   | HAL        | 570          | 3200x2400   | Carta 1300 + IGZO           |       |        | <2024 | TTL       | 61x2      |         |         |
| EC133KH1   | SC1452-NCB   | HAK        | 570          | 3200x2400   | Kaleido 3 + IGZO            |       |        | <2024 | TTL       | 61x2      |         |         |
| AC133UT1   | AA1020-NCA   |            |              | 1600x1200   | Gallery / Gallery 4000      | 35%   | 10:1   | 2020  | TTL       | 39        | 39P-A   |         |
| EL133US1   |              | EMT        |              | 1600x1200   | Spectra 3000                |       |        | <2019 | TTL       | 39        | 39P-A   | Yes     |
| EL133UR1   | EA2220-NCC   |            |              | 1600x1200   | Spectra 3000                | 33%   | 15:1   | 2020  | TTL       | 39        | 39P-A   |         |
| EL133UF1   | ED2208-NCA   | H7R        |              | 1600x1200   | Spectra 6                   | 34%   | 22:1   | 2024  | QSPI      | 60        |         |         |
| ED140TT1   | VB3300-IDA   |            | 320          | 1440x300    | Carta                       |       |        |       | TTL       |           |         |         |
| AC253TT1   | AA1020-PEA   |            |              | 3200x1800   | Gallery Plus / Gallery 4000 | 35%   | 10:1   | 2020  | MiniLVDS  | 51x2      |         |         |
| EL253EW1   | ED2208-PEA   |            |              | 3200x1800   | Spectra 6                   |       |        |       | MiniLVDS  |           |         |         |
| EC253TT1   | SD1452-PEA   |            |              | 3200x1800   | Kaleido 3 Outdoor           |       |        |       | MiniLVDS  |           |         |         |
| ED253TT1   | VB3300-PEA   |            | 320          | 3200x1800   | Carta 1.2                   |       |        |       | MiniLVDS  | 51x2      |         |         |
| ED253TT2   | VB3300-PEB   |            | 320          | 3200x1800   | Carta 1.2                   |       |        |       | MiniLVDS  | 51x2      |         |         |
| ED253TT3   | VB3300-PEC   |            | 320          | 3200x1800   | Carta 1.2                   |       |        |       | MiniLVDS  | 51x2      |         |         |
| EL253TV1   | EB2200-PEA   |            |              | 3200x1800   | Spectra 3100                |       |        |       | MiniLVDS  | 51x2      |         |         |
| ED280TT1   | VB3300-PHA   |            | 320          | 3840x1080   | Carta 1.2                   | 40%   | 12:1   | 2020  | MiniLVDS  | 51x2      |         |         |
| ED312TT2   | VA3200-QAA   |            | V220         | 2560x1440   | Pearl                       |       |        |       | TTL       | 50x4      |         |         |
| ED312TT3   | VA3200-QAB   |            | V220         | 2560x1440   | Pearl                       | 40%   | 12:1   | 2018  | TTL       | 50x4      |         |         |
| EC312TT2   | SB1452-QAA   |            | V220         | 2560x1440   | Triton                      |       |        |       | TTL       | 50x4      |         |         |
| EL315TW1   | ED2208-QBA   |            |              | 2560x1440   | Spectra 6                   |       |        |       | QSPI      |           |         |         |
| ED420TT1   | VA3200-RBA   |            | V220         | 2880x2160   | Pearl                       |       |        |       | TTL       | 50x2      |         |         |
| ED420TT3   | VB3300-RBA   |            | 320          | 2880x2160   | Carta 1.2                   | 45%   | 16:1   | 2020  | TTL       | 50x2      |         |         |
| ED420TT5   | VB3300-RBB   |            | 320          | 2880x2160   | Carta 1.2                   |       |        |       | TTL       | 50x2      |         |         |

Note: Carta 1.2 is also known as Carta 1000. If the table cell says Carta it also likely means Carta 1000 (could be 1100 as well, I don't know for sure).

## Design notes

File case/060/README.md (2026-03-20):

Glider 6 case for FDM printing
version: v1.0
2026/02/18

# About folders

## Glider_6_case_without_TP_FL

This version is designed for Glider with recycled ED060KD1 panel without touch or front light module. (If you ordered the Glider kit from Crowd Supply, this is the version you need)

## Glider_6_case_with_TP_FL

This version is designed for Glider 6 driver board with your own ED060KD1 or other 6" 34P panels with laminated touch and front light module.

# Assembly

Step1: Prepare Glider 6 module, 3D printed cases, buttons and 6x M2.5*6 screws.

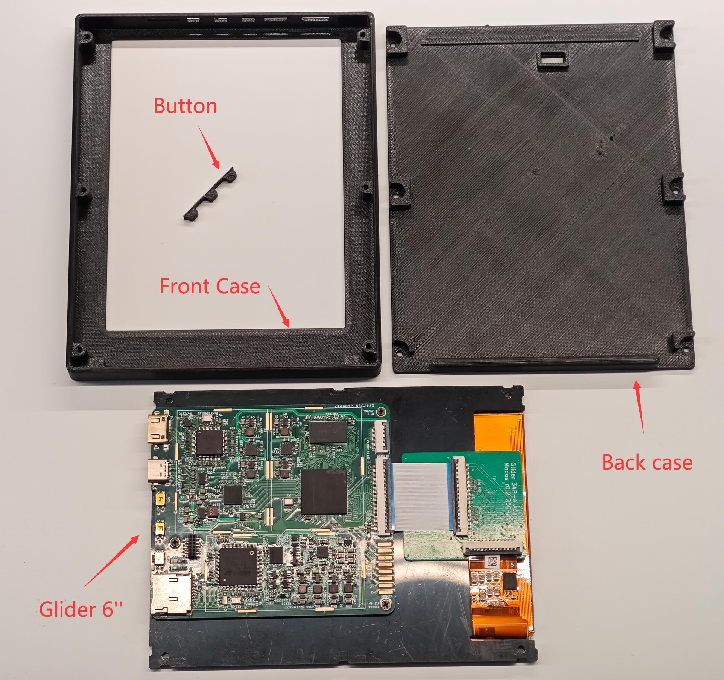
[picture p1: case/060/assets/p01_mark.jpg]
p01


About screws:  M2.5*6 flat head screws, seen below:

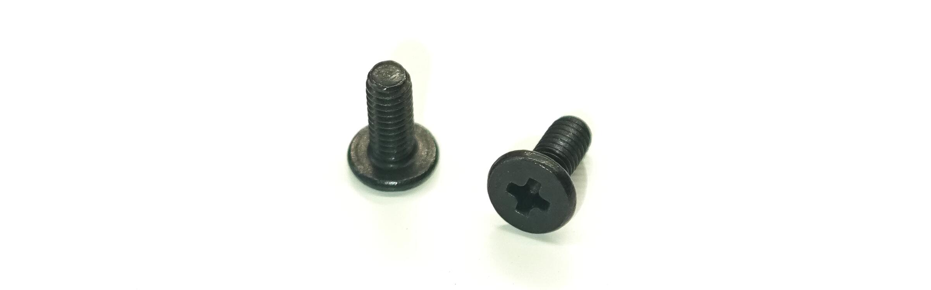
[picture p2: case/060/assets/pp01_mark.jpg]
pp01


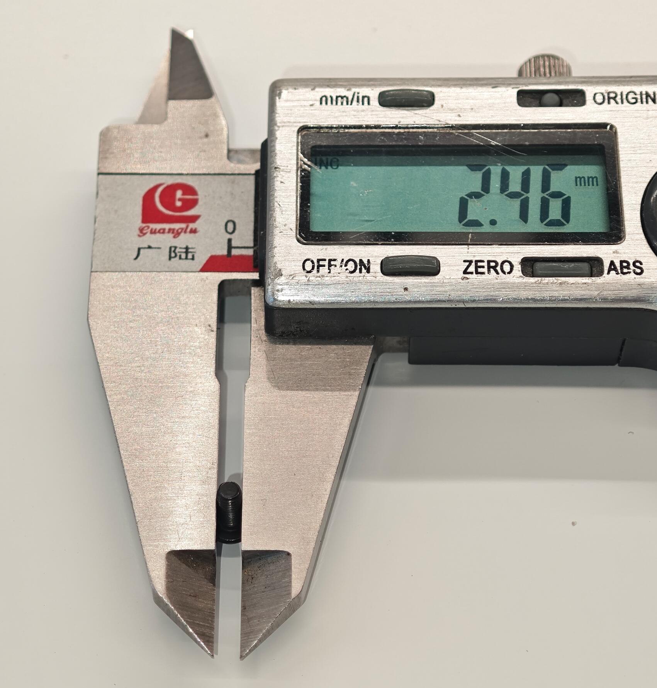
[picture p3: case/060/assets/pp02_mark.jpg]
pp02
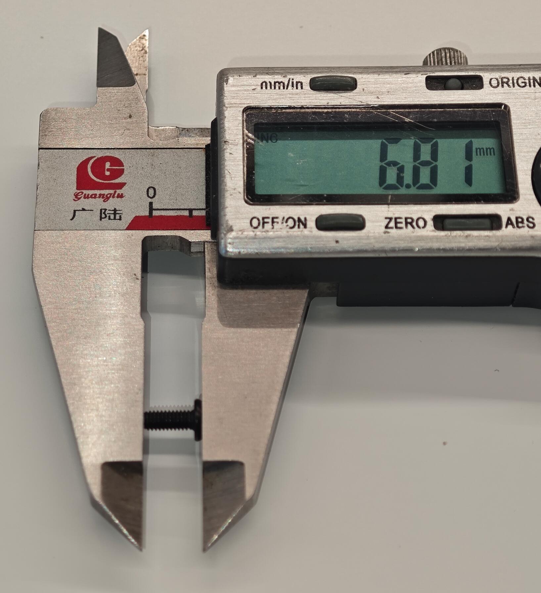
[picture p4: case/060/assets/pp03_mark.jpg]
pp03
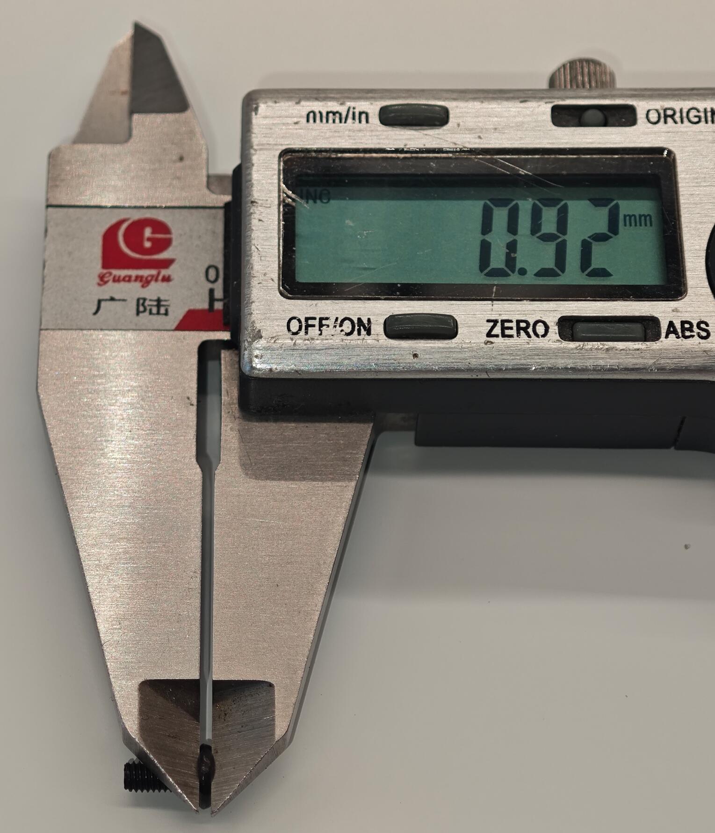
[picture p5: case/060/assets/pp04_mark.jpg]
pp04
  

About screws:  M2.5*6 flat head screws, seen below:

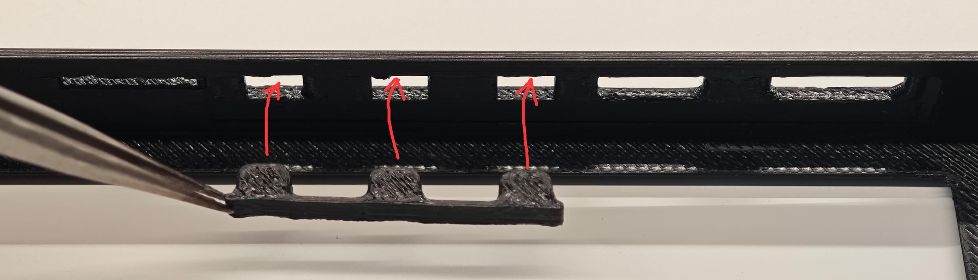
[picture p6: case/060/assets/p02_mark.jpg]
p02


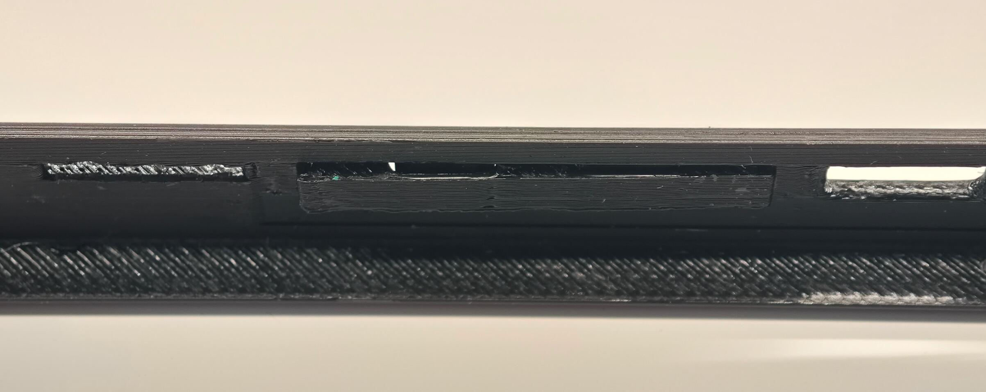
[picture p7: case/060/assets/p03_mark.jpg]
p03


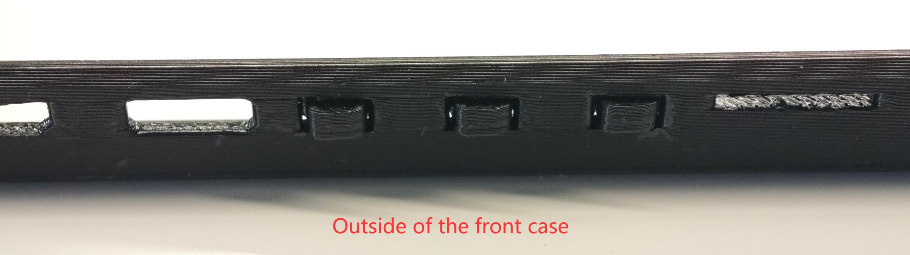
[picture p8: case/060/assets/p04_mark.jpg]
p04


Step3: Install Glider 6 module into the front case, let the USB-C and HDMI connector insert the front case.

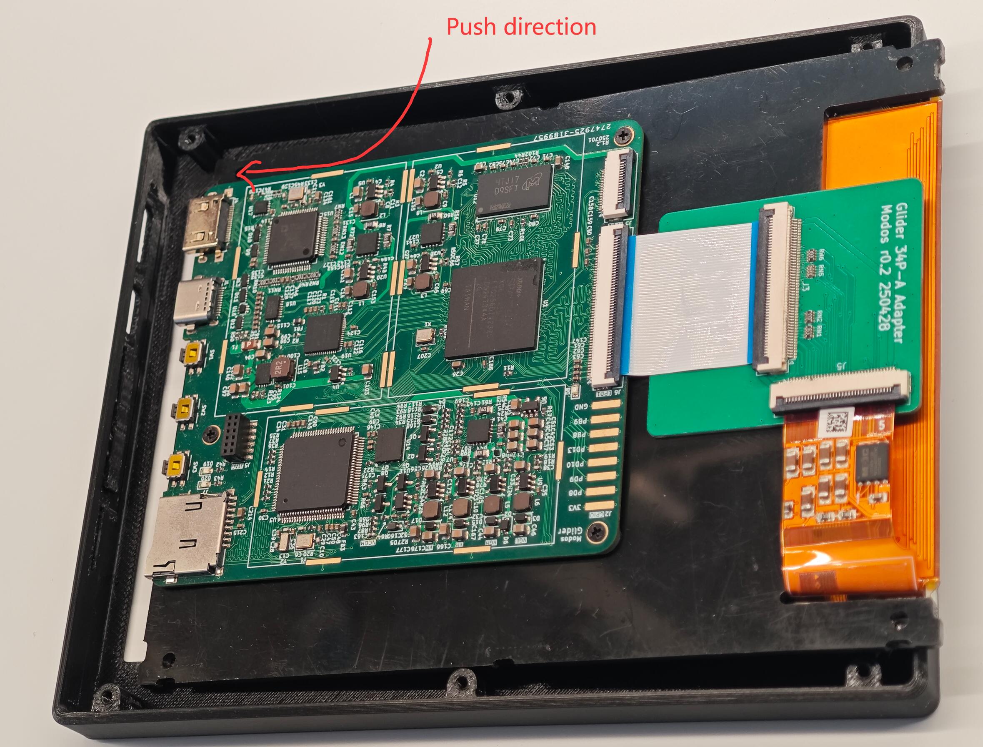
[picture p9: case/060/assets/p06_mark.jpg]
p06


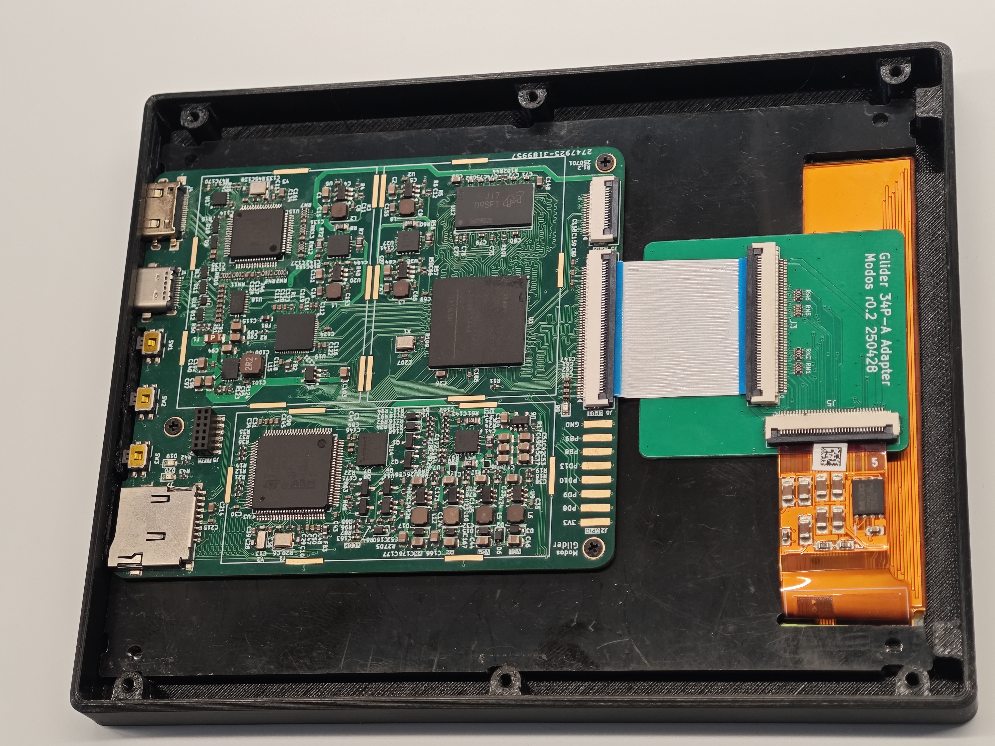
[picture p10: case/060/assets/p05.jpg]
p05


Step4: Install the back case

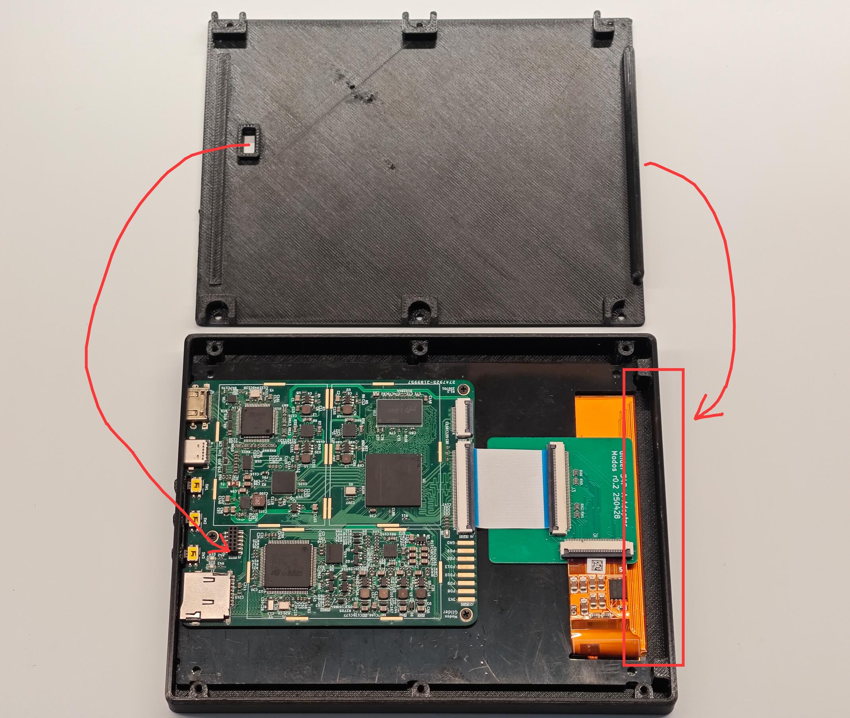
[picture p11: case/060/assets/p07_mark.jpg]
p07


p08

Step5: Install screws

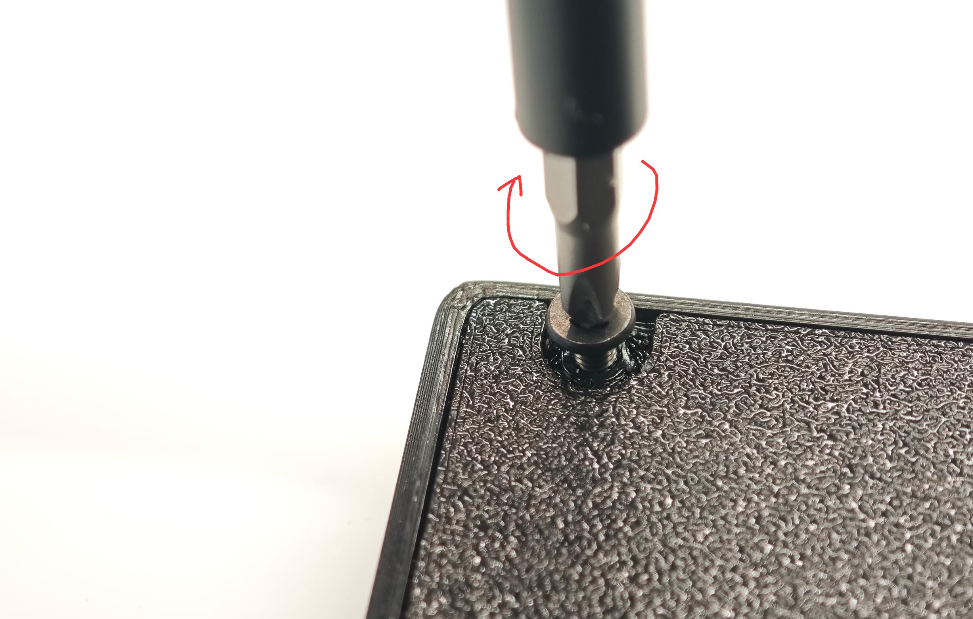
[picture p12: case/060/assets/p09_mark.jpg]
p09


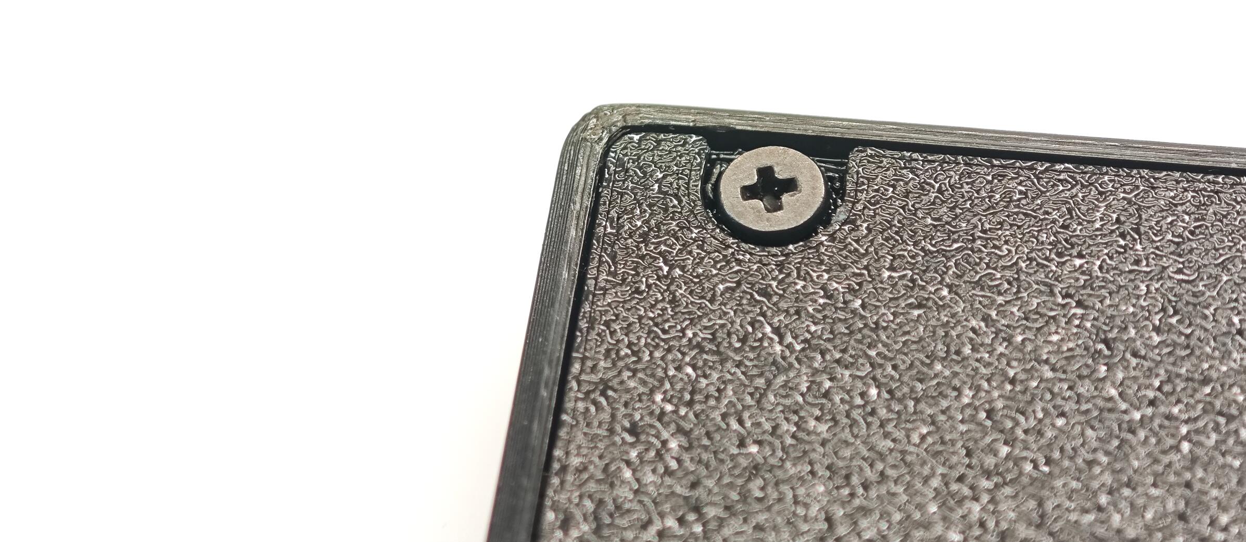
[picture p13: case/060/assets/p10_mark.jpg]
p10


p12

Step6: Check buttons and TF card slot, and finish the assembly.

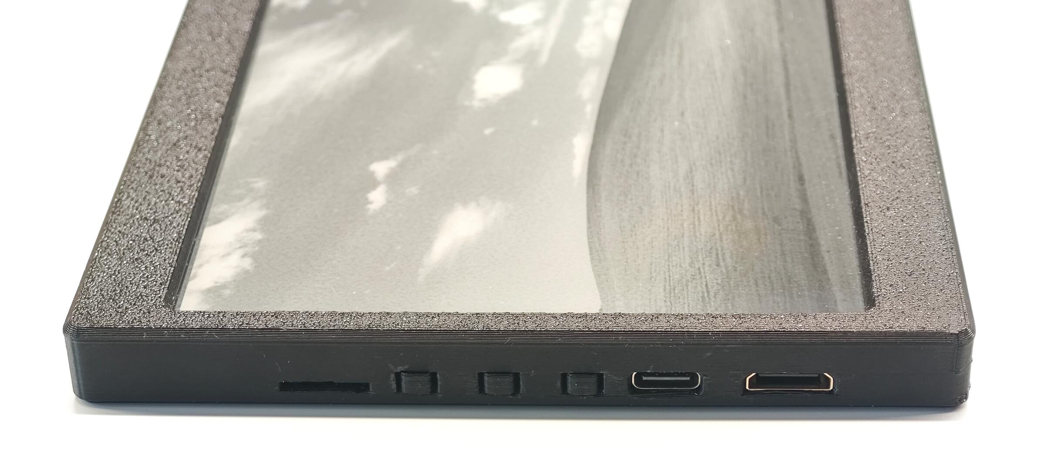
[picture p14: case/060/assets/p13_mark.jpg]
p13


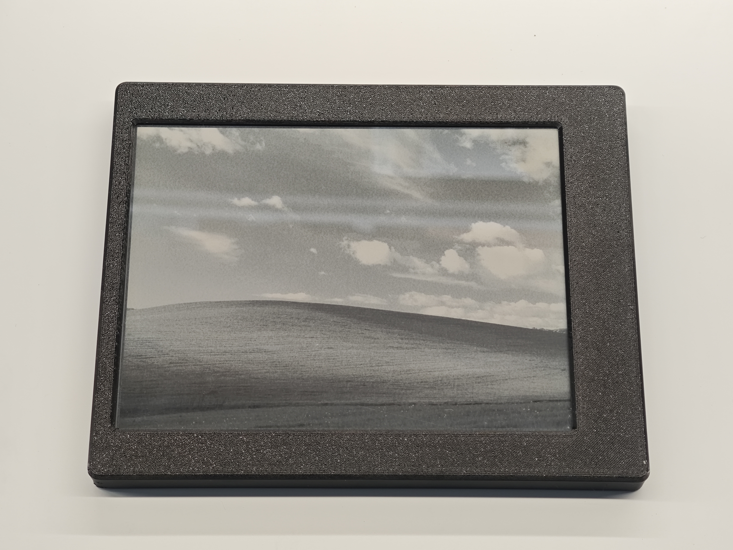
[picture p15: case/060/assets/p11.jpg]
p11


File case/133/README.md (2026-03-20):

============================================================
GLIDER13 ASSEMBLY AND SAMPLE CASE FILES - README
============================================================

# FILE DESCRIPTIONS

* Assembly.step
  This file represents the Glider13 in its "out-of-the-box" 
  state as delivered.

* Assembly w Case.step
  A reference/sample case design for the Glider13.

* Case Components
  The case consists of three files: Frame1, Back Plate1, and 
  Button1. You can 3D print these parts directly and install 
  them onto the Glider13 Assembly.

# ASSEMBLY INSTRUCTIONS

1. MOUNTING THE ASSEMBLY:
   Use at least FIVE M4*5mm CM Flat-Head screws to secure the 
   Assembly to the Back Plate.

p01

2. SECURING THE FRAME:
   Use 14 M3*6mm CM Flat-Head screws to fix the Back Plate 
   to the Frame.

p02

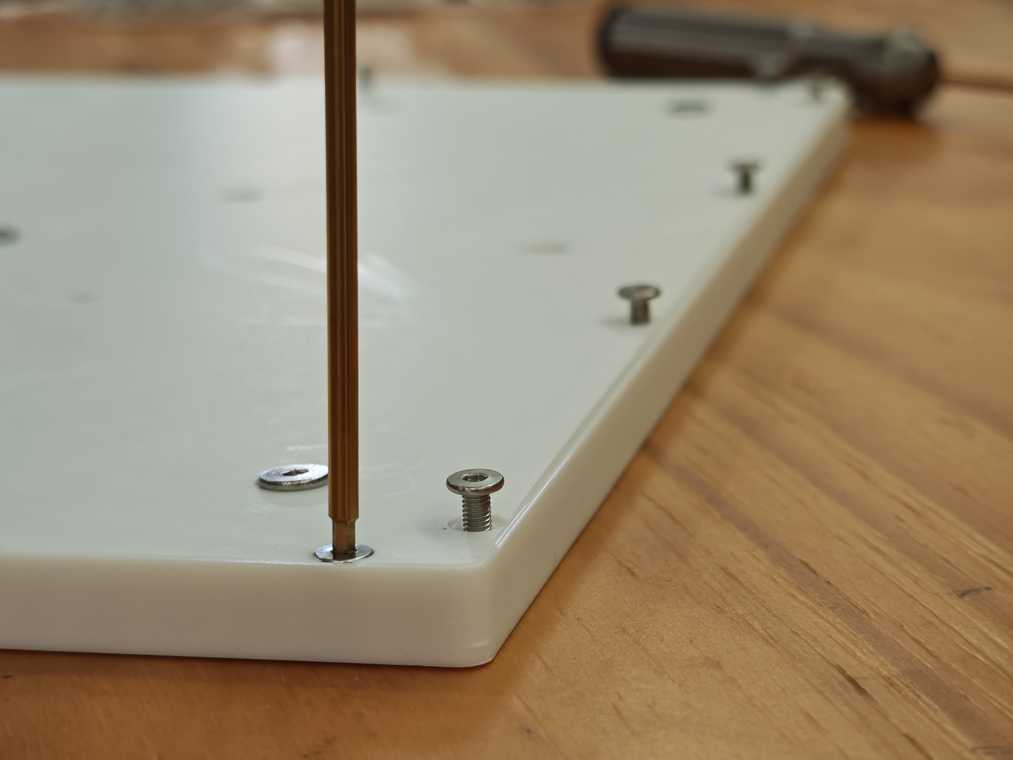
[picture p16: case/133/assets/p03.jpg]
p03


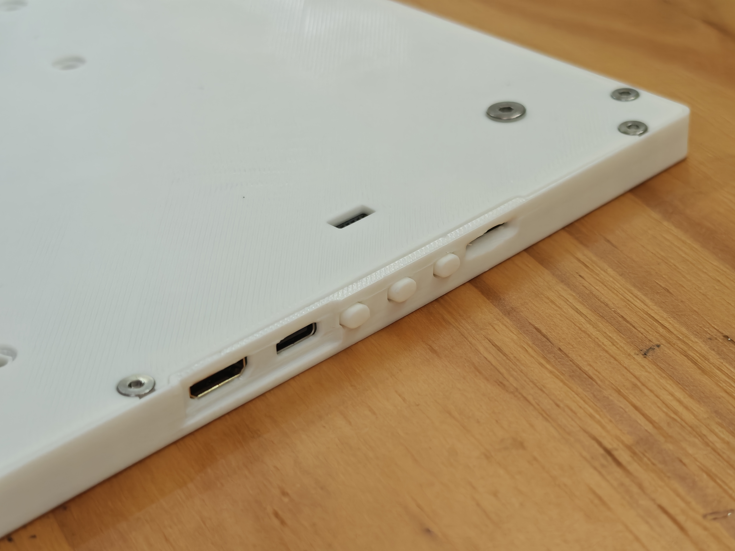
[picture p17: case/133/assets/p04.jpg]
p04


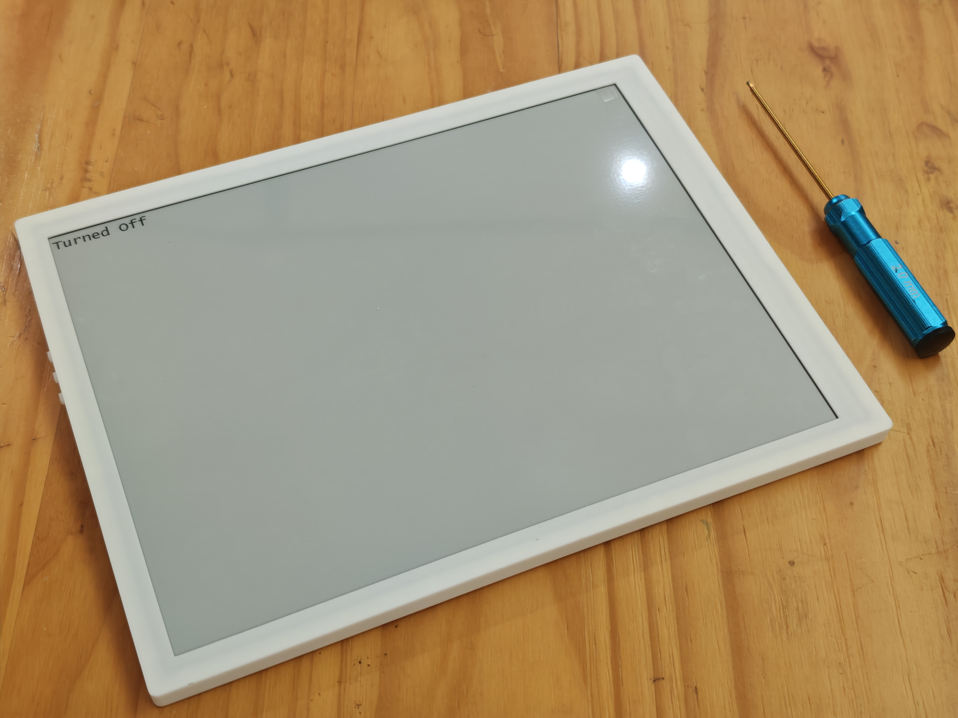
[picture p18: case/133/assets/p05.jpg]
p05


3. PRINTING CALIBRATION:
   Due to the large physical size of the components, you may 
   need to adjust the SCALING/SHRINKAGE COMPENSATION in your 
   slicer settings to account for your 3D printer's specific 
   performance.

!!!!!!!!!!!!!!!!!!!!!!!!!!!!!!!!!!!!!!!!!!!!!!!!!!!!!!!!!!!!
[!] CRITICAL WARNING:
DO NOT use M4 screws longer than the specified length when 
securing the Assembly Plate. Using excessively long screws 
may pull out the HEAT-SET INSERTS or, in the worst case, 
CRACK THE SCREEN GLASS.
!!!!!!!!!!!!!!!!!!!!!!!!!!!!!!!!!!!!!!!!!!!!!!!!!!!!!!!!!!!!

# CHANGE LOG V1.1

- UPDATE: 
  Increased screw through-hole diameters for better clearance 
  and easier fitting.

- BUG FIX: 
  Corrected M4 CM countersunk hole diameter: 
  7.2mm -> 8.2mm.

- BUG FIX: 
  Fixed M3 screw length description error (CAD model was correct): 
  M3x8mm -> M3x6mm.

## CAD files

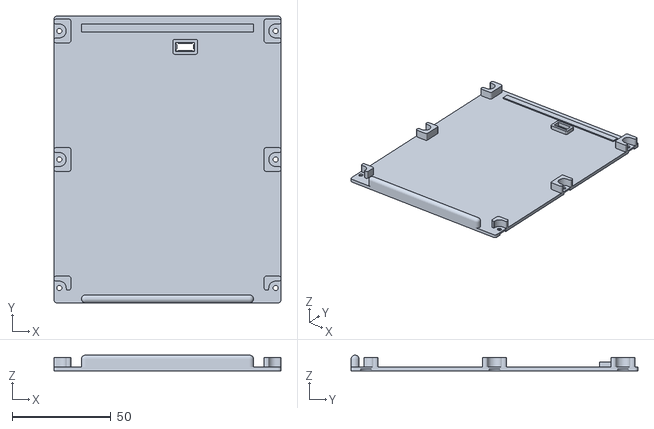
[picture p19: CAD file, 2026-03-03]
case/060/Glider_6_case_with_TP_FL/back_case/glider_6inch_back_case_v1p0.STL
114.8 x 145.0 x 8.00

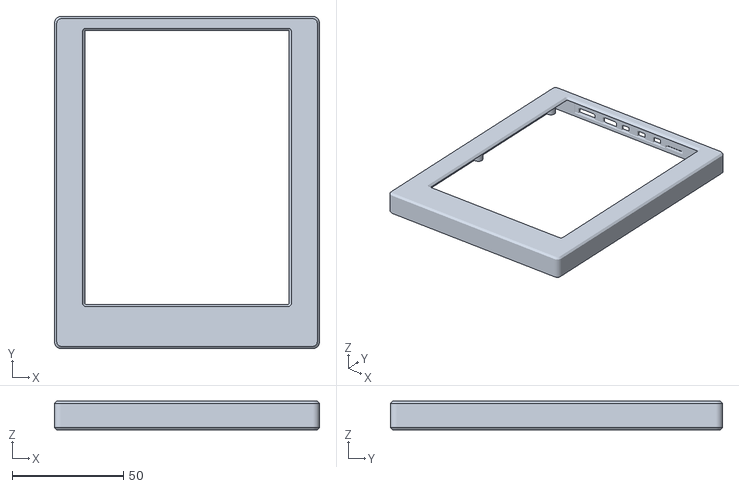
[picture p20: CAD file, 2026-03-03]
case/060/Glider_6_case_with_TP_FL/front_case/Glider_6_front_case_with_TP_FL_v1p0.STL
119.2 x 149.4 x 13.0

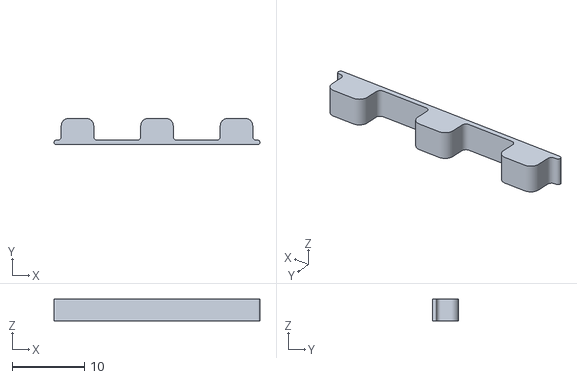
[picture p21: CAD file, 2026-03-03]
case/060/Glider_6_case_with_TP_FL/keys/Glider_6_keys_v1p0.STL
28.5 x 3.60 x 3.00

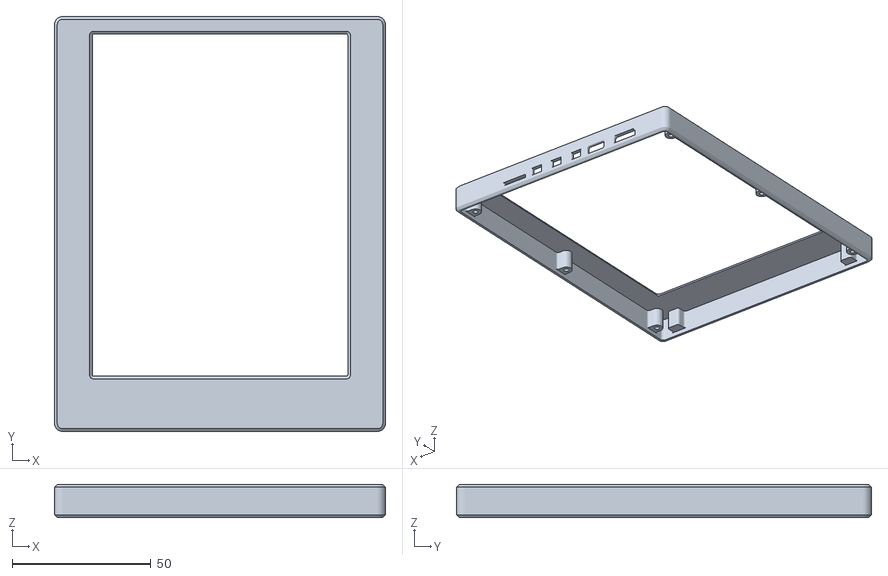
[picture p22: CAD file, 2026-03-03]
case/060/Glider_6_case_without_TP_FL/front_case/Glider_6_front_case_without_TP_FL_v1p0.STL
119.2 x 149.4 x 12.0

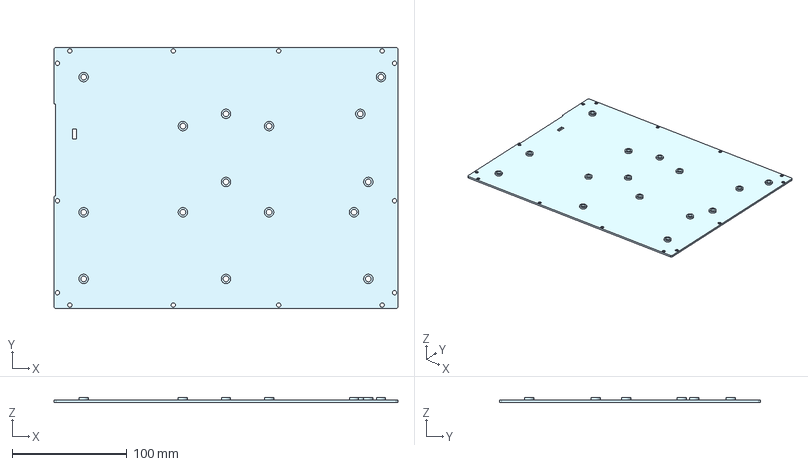
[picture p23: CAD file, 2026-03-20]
case/133/Back Plate1.stp
299.4 x 227.2 x 4.00 mm

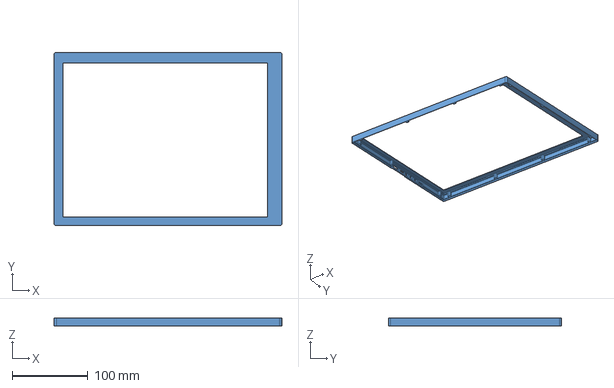
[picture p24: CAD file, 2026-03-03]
case/133/Frame1.stp
301.8 x 229.7 x 10.0 mm

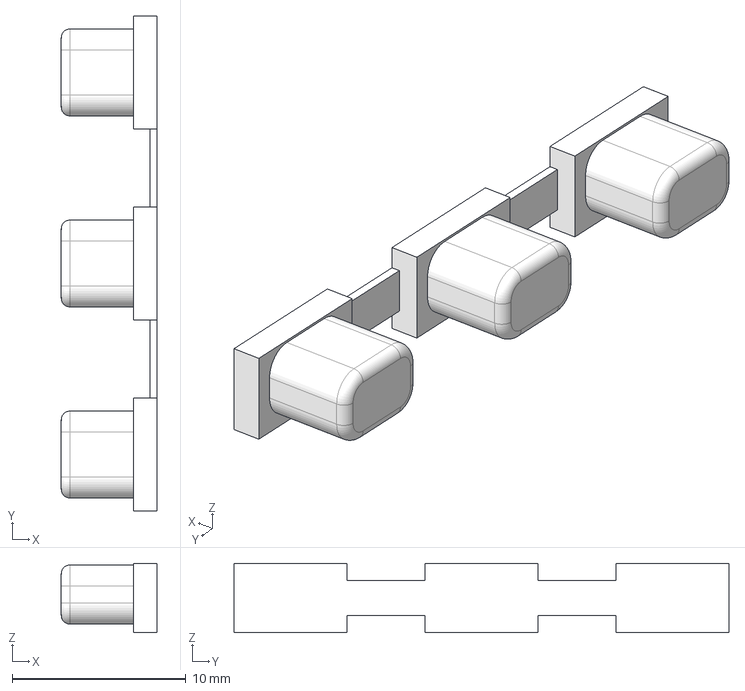
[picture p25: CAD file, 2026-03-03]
case/133/Button1.stp
5.50 x 28.5 x 4.00 mm

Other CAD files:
case/133/2D.dwg
case/133/Back Plate1 Cut.dwg
case/133/Button1.stl
case/133/Frame1.stl

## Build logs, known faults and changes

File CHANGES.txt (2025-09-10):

The following are the changes for the hardware.

R0.1
1. Initial release.

R0.2
1. Switch from ECP5 to SPARTAN6 FPGA

R0.3
1. Remove on-board 39pin/ 50pin connector, switch to 40pin connector or EPD
2. Remove DSI input connector
3. Add DisplayPort to LVDS bridge chip and DisplayPort input

R0.4
1. Use Type-C input instead of full-size DisplayPort port

R0.5
1. Switch from MAX17135 PMIC to TPS65185 PMIC
2. Switch to a different TypeC connector model
3. Added global current limit

R0.6
1. Switch to individual DCDCs for Eink power supply

Lite R0.1
1. Use DVI TMDS input in place of Type-C input and DP bridge
2. Use DCDC instead of charge pump + zener diode for lower Iq
3. Add user button
4. Add VCOM measure capability
5. Add RP2040 SWD connector

R0.7
1. Import DVI TMDS input, newly revised power supply and user button from RL0.1
2. Connect FPGA to RP2040's hardware SPI
3. Fix USB Type C mux connection

R0.8
1. Fix DVI TMDS connector pinout
2. Add FL connector

R0.9
1. Switch to 7-series FPGA
2. New 50P connector for EPD
3. Add voltage/ current monitoring for the screen and the FPGA
4. Use FFC for FL connector
5. Add jumper for RP2040 ISP
6. Add shield

R0.10
1. Switch back to 6-series FPGA
2. Switch to use STM32H750 as EC

R0.11
1. Fix main DCDC feedback resistors
2. Adjust pinout assignment for EPD again

R0.12
1. Fix buttons
2. Fix DVI HPD connection

R0.13
1. Add user GPIOs
2. Use a lower profile USB receptacle

R1.0
1. Replace LGS5148 with LGS5145

R1.1
1. Temporary fix for DVI HPD glitch

R1.2
1. Add additional power switches for positive rails
2. Add additional decap for VCOM measurement

R1.3
1. Proper fix for DVI HPD glitch
2. Fix negative rail SBD connections

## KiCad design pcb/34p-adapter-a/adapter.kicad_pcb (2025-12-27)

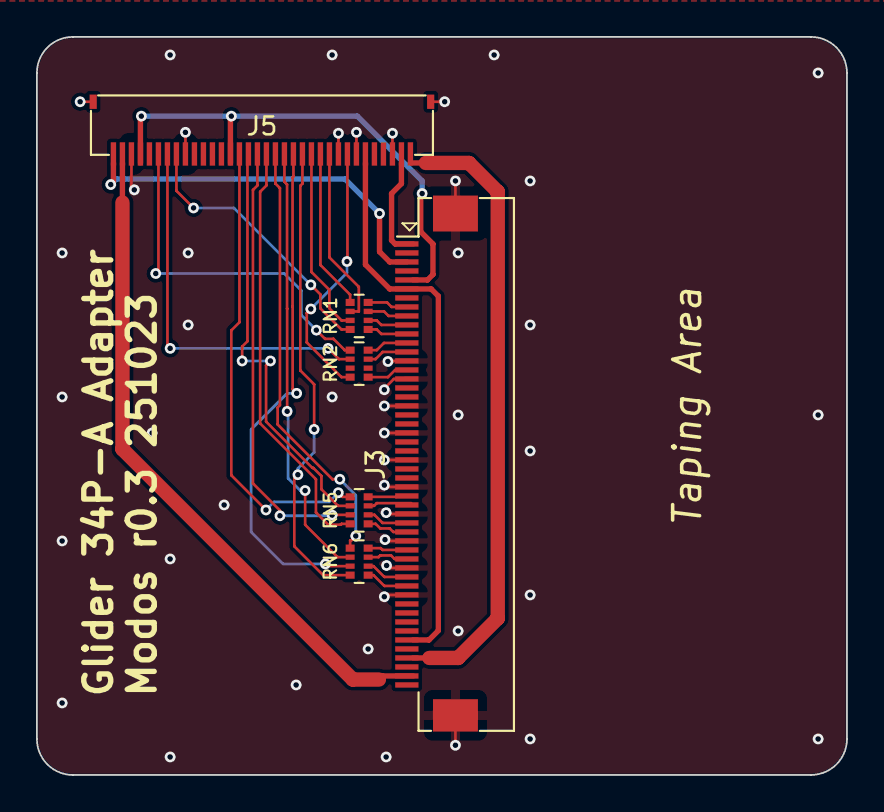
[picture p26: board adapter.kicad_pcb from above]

Board: 2 copper layers, 45.0 x 41.0 mm, 6 parts (0 on the bottom side), 37 nets.

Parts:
J3: FPC-05F-50PH20; Xunpu_FPC-05F-50PH20_1x50-1MP_P0.50mm_Horizontal_Mirrored
J5: FH34SRJ-34S-0.5SH; Hirose_FH34SRJ-34S-0.5SH_1x34-1MP_P0.50mm_Horizontal
RN1, RN2, RN5, RN6: 33; R_Array_Convex_4x0402

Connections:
+3V3: J3.6, J3.45, J5.6
+VGH: J3.3, J5.34
+VP: J3.49, J5.33
-VCOM: J3.5, J5.21, J5.31
-VGL: J3.1, J5.2
-VN: J3.47, J5.1
/ED0: J5.13, RN6.8 (R1.2)
/ED1: J5.14, RN6.7 (R2.2)
/ED2: J5.15, RN6.6 (R3.2)
/ED3: J5.16, RN6.5 (R4.2)
/ED4: J5.17, RN5.8 (R1.2)
/ED5: J5.18, RN5.7 (R2.2)
/ED6: J5.19, RN5.6 (R3.2)
/ED7: J5.20, RN5.5 (R4.2)
/ESDCLK: J5.8, RN2.8 (R1.2)
/ESDLE: J5.10, RN1.6 (R3.2)
/ESDOE: J5.11, RN1.5 (R4.2)
/GDCLK: J5.28, RN2.6 (R3.2)
/GDOE: J5.27, RN1.8 (R1.2)
/GDSP: J5.29, RN2.5 (R4.2)
/PD0: J3.39, RN6.1 (R1.1)
/PD1: J3.38, RN6.2 (R2.1)
/PD2: J3.36, RN6.3 (R3.1)
/PD3: J3.35, RN6.4 (R4.1)
/PD4: J3.33, RN5.1 (R1.1)
/PD5: J3.32, RN5.2 (R2.1)
/PD6: J3.30, RN5.3 (R3.1)
/PD7: J3.29, RN5.4 (R4.1)
/PGDCLK: J3.13, RN2.3 (R3.1)
/PGDOE: J3.11, RN1.1 (R1.1)
/PGDSP: J3.12, RN2.4 (R4.1)
/PSDCE0: J3.10, RN1.2 (R2.1)
/PSDCLK: J3.15, RN2.1 (R1.1)
/PSDLE: J3.9, RN1.3 (R3.1)
/PSDOE: J3.8, RN1.4 (R4.1)
/SDCE0: J5.12, RN1.7 (R2.2)
GND: J3.14, J3.16, J3.19, J3.22, J3.25, J3.28, J3.31, J3.34, J3.37, J3.40, J3.MP (MountPin), J5.3, J5.7, J5.9, J5.26, J5.32

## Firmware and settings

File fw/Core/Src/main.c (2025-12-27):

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
/* Includes ------------------------------------------------------------------*/
#include "main.h"
#include "cmsis_os.h"

/* USER CODE BEGIN Includes */
#include "app_main.h"
/* USER CODE END Includes */

ADC_HandleTypeDef hadc1;
DMA_HandleTypeDef hdma_adc1;

DAC_HandleTypeDef hdac1;

QSPI_HandleTypeDef hqspi;
MDMA_HandleTypeDef hmdma_quadspi_fifo_th;

SPI_HandleTypeDef hspi2;
DMA_HandleTypeDef hdma_spi2_tx;

PCD_HandleTypeDef hpcd_USB_OTG_FS;

SRAM_HandleTypeDef hsram1;

/* Definitions for defaultTask */
osThreadId_t defaultTaskHandle;
const osThreadAttr_t defaultTask_attributes = {
  .name = "defaultTask",
  .stack_size = 128 * 4,
  .priority = (osPriority_t) osPriorityNormal,
};
void SystemClock_Config(void);
static void MPU_Config(void);
static void MX_GPIO_Init(void);
static void MX_MDMA_Init(void);
static void MX_DMA_Init(void);
static void MX_ADC1_Init(void);
static void MX_DAC1_Init(void);
static void MX_FMC_Init(void);
static void MX_I2C1_Init(void);
static void MX_QUADSPI_Init(void);
static void MX_SPI2_Init(void);
static void MX_USB_OTG_FS_PCD_Init(void);
void StartDefaultTask(void *argument);

/**
  * @brief  The application entry point.
  * @retval int
  */
int main(void)
{

  /* MPU Configuration--------------------------------------------------------*/
  MPU_Config();

  /* MCU Configuration--------------------------------------------------------*/

  /* Reset of all peripherals, Initializes the Flash interface and the Systick. */
  HAL_Init();

  /* Configure the system clock */
  SystemClock_Config();

  /* Initialize all configured peripherals */
  MX_GPIO_Init();
  MX_MDMA_Init();
  MX_DMA_Init();
  MX_ADC1_Init();
  MX_DAC1_Init();
  MX_FMC_Init();
  MX_I2C1_Init();
  MX_QUADSPI_Init();
  MX_SPI2_Init();
  MX_USB_OTG_FS_PCD_Init();
  /* USER CODE BEGIN 2 */
  NVIC_SetPriority(OTG_FS_IRQn, configLIBRARY_MAX_SYSCALL_INTERRUPT_PRIORITY);
  GPIO_InitTypeDef GPIO_InitStruct;
  GPIO_InitStruct.Pin = GPIO_PIN_11 | GPIO_PIN_12;
  GPIO_InitStruct.Speed = GPIO_SPEED_FREQ_HIGH;
  GPIO_InitStruct.Mode = GPIO_MODE_AF_PP;
  GPIO_InitStruct.Pull = GPIO_NOPULL;
  GPIO_InitStruct.Alternate = GPIO_AF10_OTG2_HS;
  HAL_GPIO_Init(GPIOA, &GPIO_InitStruct);
  HAL_PWREx_EnableUSBVoltageDetector();
  __HAL_RCC_USB2_OTG_FS_CLK_ENABLE();
  // Disable VBUS sense (B device) via pin PA9
  USB_OTG_FS->GCCFG &= ~USB_OTG_GCCFG_VBDEN;

  // B-peripheral session valid override enable
  USB_OTG_FS->GOTGCTL |= USB_OTG_GOTGCTL_BVALOEN;
  USB_OTG_FS->GOTGCTL |= USB_OTG_GOTGCTL_BVALOVAL;
  HAL_PWREx_EnableUSBVoltageDetector();
  
  /* USER CODE END 2 */

  /* Init scheduler */
  osKernelInitialize();

  /* USER CODE BEGIN RTOS_MUTEX */
  /* add mutexes, ... */
  /* USER CODE END RTOS_MUTEX */

  /* USER CODE BEGIN RTOS_SEMAPHORES */
  /* add semaphores, ... */
  /* USER CODE END RTOS_SEMAPHORES */

  /* USER CODE BEGIN RTOS_TIMERS */
  /* start timers, add new ones, ... */
  /* USER CODE END RTOS_TIMERS */

  /* USER CODE BEGIN RTOS_QUEUES */
  /* add queues, ... */
  #if 0
  /* USER CODE END RTOS_QUEUES */

  /* Create the thread(s) */
  /* creation of defaultTask */
  defaultTaskHandle = osThreadNew(StartDefaultTask, NULL, &defaultTask_attributes);

  /* USER CODE BEGIN RTOS_THREADS */
  /* add threads, ... */
  #endif
  app_init();
  /* USER CODE END RTOS_THREADS */

  /* USER CODE BEGIN RTOS_EVENTS */
  /* add events, ... */
  /* USER CODE END RTOS_EVENTS */

  /* Start scheduler */
  osKernelStart();

  /* We should never get here as control is now taken by the scheduler */

  /* Infinite loop */
  /* USER CODE BEGIN WHILE */
  while (1)
  {
    /* USER CODE END WHILE */

    /* USER CODE BEGIN 3 */
  }
  /* USER CODE END 3 */
}

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
/* USER CODE BEGIN Header_StartDefaultTask */
/**
  * @brief  Function implementing the defaultTask thread.
  * @param  argument: Not used
  * @retval None
  */
/* USER CODE END Header_StartDefaultTask */
void StartDefaultTask(void *argument)
{
  /* USER CODE BEGIN 5 */
  /* Infinite loop */
  for(;;)
  {
    osDelay(1);
  }
  /* USER CODE END 5 */
}

 /* MPU Configuration */

void MPU_Config(void)
{
  MPU_Region_InitTypeDef MPU_InitStruct = {0};

  /* Disables the MPU */
  HAL_MPU_Disable();

  /** Initializes and configures the Region and the memory to be protected
  */
  MPU_InitStruct.Enable = MPU_REGION_ENABLE;
  MPU_InitStruct.Number = MPU_REGION_NUMBER0;
  MPU_InitStruct.BaseAddress = 0x0;
  MPU_InitStruct.Size = MPU_REGION_SIZE_4GB;
  MPU_InitStruct.SubRegionDisable = 0x87;
  MPU_InitStruct.TypeExtField = MPU_TEX_LEVEL0;
  MPU_InitStruct.AccessPermission = MPU_REGION_NO_ACCESS;
  MPU_InitStruct.DisableExec = MPU_INSTRUCTION_ACCESS_DISABLE;
  MPU_InitStruct.IsShareable = MPU_ACCESS_SHAREABLE;
  MPU_InitStruct.IsCacheable = MPU_ACCESS_NOT_CACHEABLE;
  MPU_InitStruct.IsBufferable = MPU_ACCESS_NOT_BUFFERABLE;

  HAL_MPU_ConfigRegion(&MPU_InitStruct);
  /* Enables the MPU */
  HAL_MPU_Enable(MPU_PRIVILEGED_DEFAULT);

}

/**
  * @brief  Period elapsed callback in non blocking mode
  * @note   This function is called  when TIM2 interrupt took place, inside
  * HAL_TIM_IRQHandler(). It makes a direct call to HAL_IncTick() to increment
  * a global variable "uwTick" used as application time base.
  * @param  htim : TIM handle
  * @retval None
  */
void HAL_TIM_PeriodElapsedCallback(TIM_HandleTypeDef *htim)
{
  if (htim->Instance == TIM2) {
    HAL_IncTick();
  }
}

/**
  * @brief  This function is executed in case of error occurrence.
  * @retval None
  */
void Error_Handler(void)
{
  /* USER CODE BEGIN Error_Handler_Debug */
  /* User can add his own implementation to report the HAL error return state */
  __disable_irq();
  while (1)
  {
  }
  /* USER CODE END Error_Handler_Debug */
}

#ifdef  USE_FULL_ASSERT
/**
  * @brief  Reports the name of the source file and the source line number
  *         where the assert_param error has occurred.
  * @param  file: pointer to the source file name
  * @param  line: assert_param error line source number
  * @retval None
  */
void assert_failed(uint8_t *file, uint32_t line)
{
  /* USER CODE BEGIN 6 */
  /* User can add his own implementation to report the file name and line number,
     ex: printf("Wrong parameters value: file %s on line %d\r\n", file, line) */
  /* USER CODE END 6 */
}
#endif /* USE_FULL_ASSERT */

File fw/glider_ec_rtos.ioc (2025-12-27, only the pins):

Mcu.UserName=STM32H750VBTx
PA0.Signal=SDMMC2_CMD
PA1.Signal=QUADSPI_BK1_IO3
PA10.Signal=GPIO_Output
PA11.Signal=USB_OTG_FS_DM
PA12.Signal=USB_OTG_FS_DP
PA2.Signal=GPIO_Output
PA3.Signal=GPIO_Output
PA4.Signal=COMP_DAC11_group
PA5.Signal=COMP_DAC12_group
PA6.Signal=ADCx_INP3
PA7.Signal=ADCx_INP7
PA9.Signal=GPIO_Output
PB0.Signal=ADCx_INP9
PB1.Signal=ADCx_INP5
PB10.Signal=QUADSPI_BK1_NCS
PB12.Signal=GPIO_Output
PB13.Signal=SPI2_SCK
PB14.Signal=SDMMC2_D0
PB15.Signal=SDMMC2_D1
PB2.Signal=QUADSPI_CLK
PB5.Signal=GPIO_Input
PB6.Signal=I2C1_SCL
PB7.Signal=I2C1_SDA
PC1.Signal=SDMMC2_CK
PC10.Signal=GPIO_Output
PC11.Signal=GPIO_Input
PC12.Signal=GPIO_Output
PC2_C.Signal=SPI2_MISO
PC3_C.Signal=SPI2_MOSI
PC4.Signal=ADCx_INP4
PC5.Signal=ADCx_INP8
PC7.Signal=FMC_NE1
PC9.Signal=QUADSPI_BK1_IO0
PD0.Signal=FMC_D2_DA2
PD1.Signal=FMC_D3_DA3
PD11.Signal=FMC_A16_CLE
PD12.Signal=QUADSPI_BK1_IO1
PD14.Signal=FMC_D0_DA0
PD15.Signal=FMC_D1_DA1
PD2.Signal=GPIO_Output
PD3.Signal=GPIO_Output
PD4.Signal=FMC_NOE
PD5.Signal=FMC_NWE
PD6.Signal=GPIO_Output
PD7.Signal=GPIO_Input
PE0.Signal=GPIO_Output
PE1.Signal=GPIO_Output
PE10.Signal=FMC_D7_DA7
PE11.Signal=GPIO_Output
PE12.Signal=GPIO_Output
PE15.Signal=GPIO_Output
PE2.Signal=QUADSPI_BK1_IO2
PE3.Signal=GPIO_Input
PE4.Signal=GPIO_Input
PE7.Signal=FMC_D4_DA4
PE8.Signal=FMC_D5_DA5
PE9.Signal=FMC_D6_DA6

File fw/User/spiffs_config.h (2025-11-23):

#ifndef SPIFFS_CONFIG_H_
#define SPIFFS_CONFIG_H_

// Following includes are for the linux test build of spiffs
// These may/should/must be removed/altered/replaced in your target
#include <stdio.h>
#include <stdlib.h>
#include <string.h>
#include <stdint.h>
#include <stddef.h>

#include "platform.h"
#include "syslog.h"
extern SemaphoreHandle_t spiffs_lock;

// Set generic spiffs debug output call.
#ifndef SPIFFS_DBG
//#define SPIFFS_DBG(...) syslog_printf(__VA_ARGS__)
#define SPIFFS_DBG(...)
#endif
// Set spiffs debug output call for garbage collecting.
#ifndef SPIFFS_GC_DBG
//#define SPIFFS_GC_DBG(...) syslog_printf(__VA_ARGS__)
#define SPIFFS_GC_DBG(...)
#endif
// Set spiffs debug output call for caching.
#ifndef SPIFFS_CACHE_DBG
//#define SPIFFS_CACHE_DBG(...) syslog_printf(__VA_ARGS__)
#define SPIFFS_CACHE_DBG(...)
#endif
// Set spiffs debug output call for system consistency checks.
#ifndef SPIFFS_CHECK_DBG
//#define SPIFFS_CHECK_DBG(...) syslog_printf(__VA_ARGS__)
#define SPIFFS_CHECK_DBG(...)
#endif

// Enable/disable API functions to determine exact number of bytes
// for filedescriptor and cache buffers. Once decided for a configuration,
// this can be disabled to reduce flash.
#ifndef SPIFFS_BUFFER_HELP
#define SPIFFS_BUFFER_HELP              0
#endif

// Enables/disable memory read caching of nucleus file system operations.
// If enabled, memory area must be provided for cache in SPIFFS_mount.
#ifndef  SPIFFS_CACHE
#define SPIFFS_CACHE                    1
#endif
#if SPIFFS_CACHE
// Enables memory write caching for file descriptors in hydrogen
#ifndef  SPIFFS_CACHE_WR
#define SPIFFS_CACHE_WR                 0
#endif

// Enable/disable statistics on caching. Debug/test purpose only.
#ifndef  SPIFFS_CACHE_STATS
#define SPIFFS_CACHE_STATS              0
#endif
#endif

// Always check header of each accessed page to ensure consistent state.
// If enabled it will increase number of reads, will increase flash.
#ifndef SPIFFS_PAGE_CHECK
#define SPIFFS_PAGE_CHECK               3
#endif

// Define maximum number of gc runs to perform to reach desired free pages.
#ifndef SPIFFS_GC_MAX_RUNS
#define SPIFFS_GC_MAX_RUNS              3
#endif

// Enable/disable statistics on gc. Debug/test purpose only.
#ifndef SPIFFS_GC_STATS
#define SPIFFS_GC_STATS                 0
#endif

// Garbage collecting examines all pages in a block which and sums up
// to a block score. Deleted pages normally gives positive score and
// used pages normally gives a negative score (as these must be moved).
// To have a fair wear-leveling, the erase age is also included in score,
// whose factor normally is the most positive.
// The larger the score, the more likely it is that the block will
// picked for garbage collection.

// Garbage collecting heuristics - weight used for deleted pages.
#ifndef SPIFFS_GC_HEUR_W_DELET
#define SPIFFS_GC_HEUR_W_DELET          (5)
#endif
// Garbage collecting heuristics - weight used for used pages.
#ifndef SPIFFS_GC_HEUR_W_USED
#define SPIFFS_GC_HEUR_W_USED           (-1)
#endif
// Garbage collecting heuristics - weight used for time between
// last erased and erase of this block.
#ifndef SPIFFS_GC_HEUR_W_ERASE_AGE
#define SPIFFS_GC_HEUR_W_ERASE_AGE      (50)
#endif

// Object name maximum length.
#ifndef SPIFFS_OBJ_NAME_LEN
#define SPIFFS_OBJ_NAME_LEN             (32)
#endif

// Size of buffer allocated on stack used when copying data.
// Lower value generates more read/writes. No meaning having it bigger
// than logical page size.
#ifndef SPIFFS_COPY_BUFFER_STACK
#define SPIFFS_COPY_BUFFER_STACK        (64)
#endif

// Enable this to have an identifiable spiffs filesystem. This will look for
// a magic in all sectors to determine if this is a valid spiffs system or
// not on mount point. If not, SPIFFS_format must be called prior to mounting
// again.
#ifndef SPIFFS_USE_MAGIC
#define SPIFFS_USE_MAGIC                (1)
#endif

#if SPIFFS_USE_MAGIC
// Only valid when SPIFFS_USE_MAGIC is enabled. If SPIFFS_USE_MAGIC_LENGTH is
// enabled, the magic will also be dependent on the length of the filesystem.
// For example, a filesystem configured and formatted for 4 megabytes will not
// be accepted for mounting with a configuration defining the filesystem as 2
// megabytes.
#ifndef SPIFFS_USE_MAGIC_LENGTH
#define SPIFFS_USE_MAGIC_LENGTH         (1)
#endif
#endif

// SPIFFS_LOCK and SPIFFS_UNLOCK protects spiffs from reentrancy on api level
// These should be defined on a multithreaded system

// define this to entering a mutex if you're running on a multithreaded system
#ifndef SPIFFS_LOCK
#define SPIFFS_LOCK(fs)			xSemaphoreTake(spiffs_lock, portMAX_DELAY);
#endif
// define this to exiting a mutex if you're running on a multithreaded system
#ifndef SPIFFS_UNLOCK
#define SPIFFS_UNLOCK(fs)		xSemaphoreGive(spiffs_lock);
#endif
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

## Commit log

2025-09-10 Example printable cases for Glider kits
    [Back.dwg, Front.dwg, case.FCStd]
2025-09-10 PCB r1p3
    [adapter.kicad_pcb, adapter.kicad_sch, dp_in.kicad_sch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]
2025-12-27 Improve PD reliability; Fix USB descriptors
    [board.c, config.c, glider_ec_rtos.ioc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]
2025-12-27 Sync local PCB changes
    [adapter.kicad_pcb, adapter.kicad_sch, dp_in.kicad_sch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]
2026-03-03 Upload updated case designs
    [2D.dwg, Back Plate1 Cut.dwg, Back Plate1.stp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]
2026-03-20 Update case design
    [2D.dwg, Back Plate1.stp]

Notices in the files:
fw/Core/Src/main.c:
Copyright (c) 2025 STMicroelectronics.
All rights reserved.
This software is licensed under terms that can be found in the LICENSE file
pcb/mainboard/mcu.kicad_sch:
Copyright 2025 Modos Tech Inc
